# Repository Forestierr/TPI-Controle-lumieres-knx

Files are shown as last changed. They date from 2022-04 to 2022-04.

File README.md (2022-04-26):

# TPI_Forestier_Gestion_Lumiere_KNX #

Wiki: [Wiki](https://github.com/Forestierr/TPI-Controle-lumieres-knx/wiki)

Énoncé du travail d'examen: [Énoncé du travail](https://github.com/Forestierr/TPI-Controle-lumieres-knx/blob/main/1_Documentation/Enoncé%20du%20travail%20d'examen.pdf)

## Travail avant TPI ##

Wiki: [Wiki](https://github.com/Forestierr/Controle-lumieres-knx/wiki)

GitHub: [GitHub](https://github.com/Forestierr/Controle-lumieres-knx)

# Description du travail d'examen #

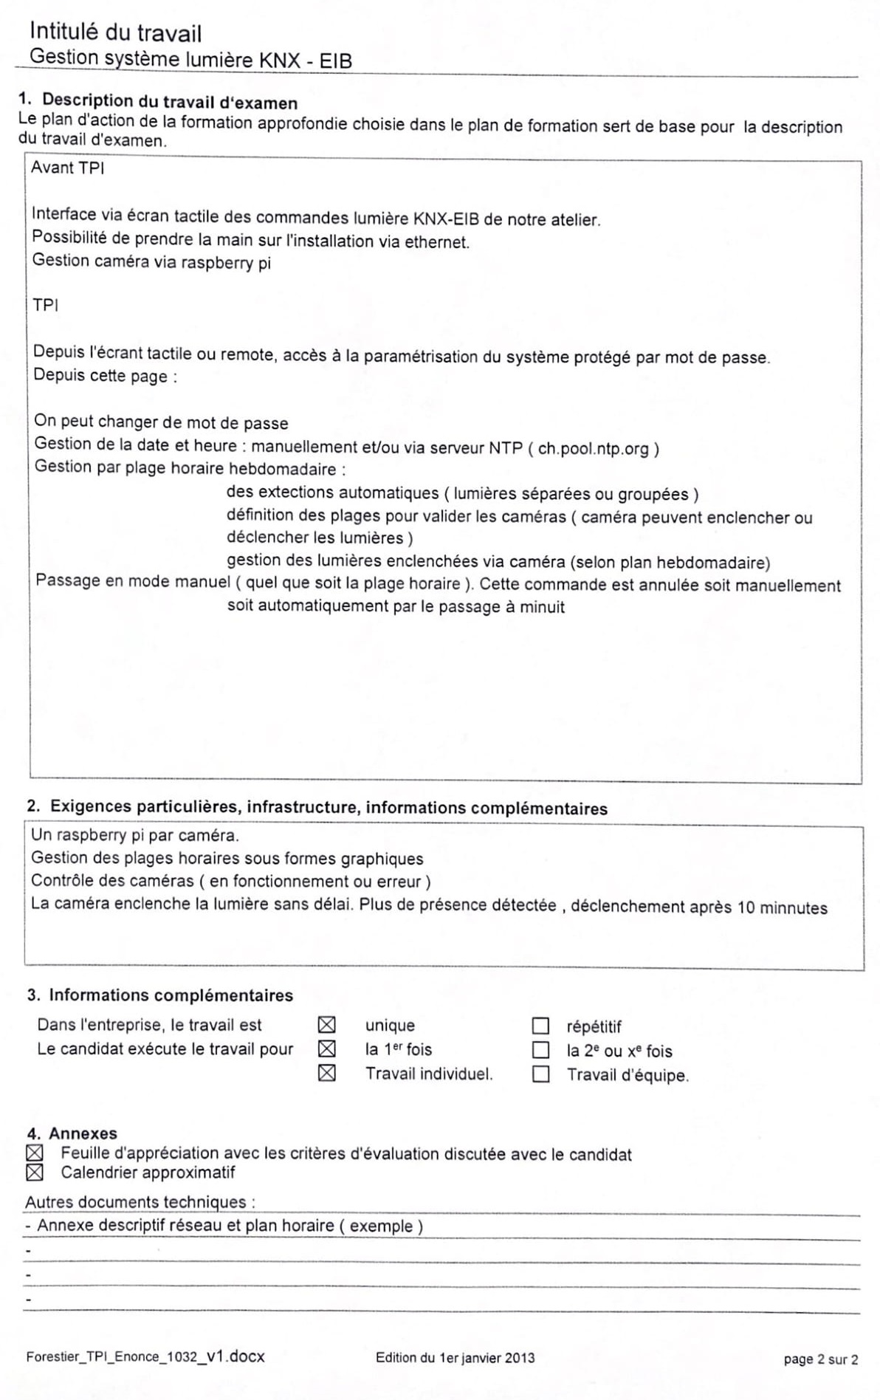
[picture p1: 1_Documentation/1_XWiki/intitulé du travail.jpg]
Cahier des charges


---

<div align="center">
    <i>Robin Forestier</i>
</div>

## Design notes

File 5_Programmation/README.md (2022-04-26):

# 5_Programmation #

Ce dossier contient l'entièreté de la programmation du projet.
Il y a deux sous dossier: camera et server. Le dosiier camera contient tous les codes et tous les testes pour le Rasperry Pi avec caméra.
Le dossier server contient les code pour le Raspberry Pi server (avec écran tactile).

---

Robin Forestier 2022

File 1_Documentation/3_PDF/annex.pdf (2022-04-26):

### Annex – Programmation – Caméra – Sélection Des Portes

5_Programmation/camera/Detetcion_Porte/door_setect.py

### Annex – Programmation – Caméra – Détection Des Portes

5_Programmation/camera/Detetcion_Porte/door_detect.py

### Annex – Programmation – Caméra – Détection Des Personnes

5_Programmation/camera/Detection_Personne/personne_detect.py

### Annex – Programmation – Caméra – Tracking Des Personnes

5_Programmation/camera/Detection_Personne/personne_tracking.py

### Annex – Programmation – Caméra – Détection Des Entrées

5_Programmation/camera/Detection_Entry/entry_detect.py

### Annex – Programmation – Caméra – Détection Des Personne 2

5_Programmation/camera/Detection_Personne_2/personne_detect.py

### Annex – Programmation – Caméra – Tracking Des Personne 2

5_Programmation/camera/Detection_Personne_2/personne_tracking.py

### Annex – Programmation – Caméra – Détection Des Entrées 2

5_Programmation/camera/Detection_Entry_2/entry_detect.py

### Annex – Programmation – Serveur – Main

5_Programmation/server/main.py

### Annex – Programmation – Serveur – WSGI

5_Programmation/server/wsgi.py

### Annex – Programmation – Serveur – Table

5_Programmation/server/table/table.py

### Annex – Programmation – Serveur – HTML – Login 2

5_Programmation/server/templates/login2.html

### Annex – Programmation – Serveur – HTML – Settings

5_Programmation/server/templates/settings.html

### Annex – Programmation – Serveur – CSS – Settings

5_Programmation/server/static/settings.css

### Annex – Programmation – Serveur – CSS – Login 2

5_Programmation/server/static/login2.css

### Annex – Programmation – Serveur – Test

5_Programmation/server/test/flask_test.py

### Annex – Programmation – Caméra – Test

5_Programmation/camera/test/main.py

### Annex – Programmation – Caméra – Test Communication

5_Programmation/camera/test/test_communication.py

### Annex – Planning

1_Documentation/Planning_TPI_FOR_v2.xls

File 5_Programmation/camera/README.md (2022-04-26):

# Caméra #

## Dossiers ##

### test ###

Dossier contenant un fichier de test d'OpenCV.
> cd test
> 
> python main.py

### Detection_Porte ###

**door_select.py** fichier utilisé pour sélectionner la position des portes.

**door_detect.py** fichier utilisé pour détecter les porte avec le template matching.

### Detection_Personne ##

**personne_detect.py** fichier utilisé pour détecter des personnes en mouvement (avec backgroundSubtractorKNN).

**personne_tracking.py** fichier utilisé pour calculer l'angle de déplacement d'une personne.

### Detection_Entry ###

**entry_detect.py** fichier utiliser pour détecter les entrées. Ce fichier utilise la detection des portes et des 
personnes.

### Detection_Personne_2 ###

Ce dossier contient le fichier de détection réaliser pour l'amélioration du système.
La détection se fait donc par le dessu de la porte ou par le côté.

**personne_detect.py** fichier utilisé pour détecter des personnes en mouvement (avec backgroundSubtractorMOG2).

### Detection_Entry_2 ###

Ce dossier contient le fichier de détection réaliser pour l'amélioration du système.
Il fonctionne avec **Detection_Personne_2**.

**entry_detect_2.py** fichier utiliser pour détecter les entrées. Ce fichier utilise la detection des portes et des
personnes.

---

Robin Forestier

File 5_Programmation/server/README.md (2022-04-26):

# Elo light control #

## But : ##

Le but de ce project est de controller les lumières de l'atelier avec un interface graphique sur l'écran tactile du Raspberry Pi 3B+.

## Test ##

./test/flask_test.py

Lancer ce fichier pour tester le serveur flask.

## launching the app ##

sudo python3 main.py

/!\ sudo est utilisé (sur linux) pour authoriser l'utilisaton du port 80.

Pour utiliser le server complétement référez vous aux XWiki.

## Liens ##

[Gitlab](http://172.16.32.230/Forestier/controle-des-lumieres-knx)

[XWiki](https://xwiki.serverelo.org/xwiki/bin/view/Centre%20de%20Formation%20ELO/Projets/Controle%20des%20lumières%20KNX/)

## ##

Robin Forestier 2021 / 2022

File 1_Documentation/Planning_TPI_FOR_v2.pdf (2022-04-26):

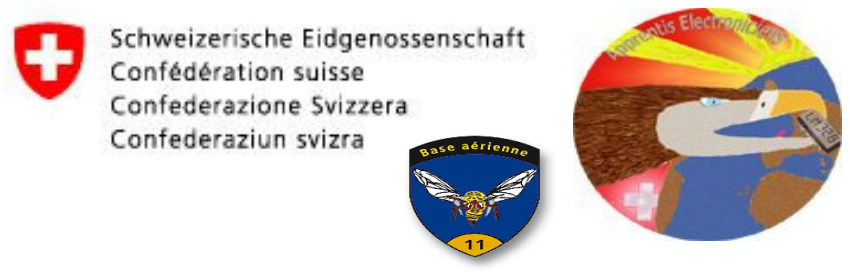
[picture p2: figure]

Tâches | Jours | Mon 07/Mar | Tue 08/Mar | Wed 09/Mar | Thu 10/Mar | Fri 11/Mar
Heures | Mat | Ap. Mi | Mat | Ap. Mi | Mat | Ap. Mi | Mat | Ap. Mi | Mat | Ap. Mi
Planification du projet

C

o

urs

E

P

SIC

### Robin Forestier

Correction et amélioration
Documentation | | | | | | Tot Sem | Total
Heures programmées | 08:00 | 08:00 | 08:00 | 00:00 | 00:00 | 24:00 | 24:00

Gestion des erreurs de communication

Communication via WIFI

Test de l'interface et optimisation

Mise en page CSS

Implémentation du mode manuelle

Création des tableaux de plage horaire

Création de la page HTML

Gestion de la date et de l'heure

Détection des portes
Détection des personnes
Détection des entrées et des sorties Ajustement pour la vision nocturne

Installation des Rasberry Pi

C

o

urs

E

P

SIC

Planning - Semaine 1 | Temps planifié Temps réel

Tâches | Jours | Mon 14/Mar | Tue 15/Mar | Wed 16/Mar | Thu 17/Mar | Fri 18/Mar
Heures | Mat | Ap. Mi | Mat | Ap. Mi | Mat | Ap. Mi | Mat | Ap. Mi | Mat | Ap. Mi
Planification du projet

### Robin Forestier

Test de l'interface et optimisation

Communication via WIFI

Gestion des erreurs de communication

Correction et amélioration

Documentation | | | | | | Tot Sem | Total
Heures programmées | 08:00 | 08:00 | 08:00 | 00:00 | 00:00 | 24:00 | 48:00

Mise en page CSS

Détection des portes

Détection des personnes

Détection des entrées et des sorties Ajustement pour la vision nocturne

Gestion de la date et de l'heure

Création de la page HTML

Création des tableaux de plage horaire

Implémentation du mode manuelle

Installation des Rasberry Pi

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
Planning – Semaine 2 | Temps planifié Temps réel

Tâches | Jours | Mon 21/Mar | Tue 22/Mar | Wed 23/Mar | Thu 24/Mar | Fri 25/Mar
Heures | Mat | Ap. Mi | Mat | Ap. Mi | Mat | Ap. Mi | Mat | Ap. Mi | Mat | Ap. Mi
Planification du projet

Installation des Rasberry Pi

### Robin Forestier

Communication via WIFI

Gestion des erreurs de communication

Correction et amélioration

Documentation | | | | | | Tot Sem | Total
Heures programmées | 08:00 | 08:00 | 08:00 | 00:00 | 00:00 | 24:00 | 72:00

Test de l'interface et optimisation

Création de la page HTML

Création des tableaux de plage horaire

Implémentation du mode manuelle

Mise en page CSS

Gestion de la date et de l'heure

Détection des entrées et des sorties Ajustement pour la vision nocturne

Détection des personnes

Détection des portes

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
Planning – Semaine 3 | Temps planifié Temps réel

Tâches | Jours | Mon 28/Mar | Tue 29/Mar | Wed 30/Mar | Thu 31/Mar | Fri 01/Apr
Heures | Mat | Ap. Mi | Mat | Ap. Mi | Mat | Ap. Mi | Mat | Ap. Mi | Mat | Ap. Mi
Planification du projet

Installation des Rasberry Pi

### Robin Forestier

Communication via WIFI

Gestion des erreurs de communication

Correction et amélioration

Documentation | | | | | | Tot Sem | Total
Heures programmées | 08:00 | 08:00 | 08:00 | 00:00 | 00:00 | 24:00 | 96:00

Test de l'interface et optimisation

Création de la page HTML

Création des tableaux de plage horaire

Implémentation du mode manuelle

Mise en page CSS

Gestion de la date et de l'heure

Détection des entrées et des sorties Ajustement pour la vision nocturne

Détection des personnes

Détection des portes

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
Planning – Semaine 4 | Temps planifié Temps réel

Tâches | Jours | Mon 04/Apr | Tue 05/Apr | Wed 06/Apr | Thu 07/Apr | Fri 08/Apr
Heures | Mat | Ap. Mi | Mat | Ap. Mi | Mat | Ap. Mi | Mat | Ap. Mi | Mat | Ap. Mi
Planification du projet

Installation des Rasberry Pi

Fin

d

u

T

PI

### Robin Forestier

C

o

urs

E

P

SIC

Communication via WIFI

Gestion des erreurs de communication

Correction et amélioration

Documentation | | | | | | Tot Sem | Total
Heures programmées | 08:00 | 08:00 | 00:00 | 00:00 | 00:00 | 16:00 | 112:00

Test de l'interface et optimisation

Création de la page HTML

Création des tableaux de plage horaire

Implémentation du mode manuelle

Mise en page CSS

Gestion de la date et de l'heure

Détection des entrées et des sorties Ajustement pour la vision nocturne

Détection des personnes

Détection des portes

C

o

urs

E

P

SIC

Planning – Semaine 5 | Temps planifié Temps réel

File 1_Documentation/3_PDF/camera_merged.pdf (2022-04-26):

1 """door_select.py | Robin Forestier | 07.03.2022
2
3 This file is used to select doors in images.
4 """
5
6 | import | | cv2
7 | import | | numpy | | as | | np
8 | import | | pickle
9
10
11 | class | | DoorSelect:
12 """The DoorSelect class is a class that contains a method that allows the user
| to select a door."""
13 | | def | | __init__(self, | | | | | img | | = | | None):
14 """ __init__ is the constructor of the class DoorSelect.
15 :param img: the image that will be used to select the doors. 16 :type img: numpy.ndarray
17 """
18
19 # the image
20 | | self.img | | | | = | | img
21
22
23 | | self.doors | | | | = | | []
24 """Doors
25 List containing the 4 corners coordinations of each door. 26 """
27
28 | | self.fleches | | | | = | | []
29 """Fleches
30 List containing the coordination of the arrowhead.
31 """
32
33 # number of point already placed (return to 0 after each door)
34 | | self.npoints | | | | = | | 0
35
36 | | if | | img | | is | | not | | None:
37 # a copy of the clean image (used when you delete a selection)
38 | | self.img_copy | | | | = | | img.copy()
39 cv2.namedWindow("door select")
40 | | cv2.setMouseCallback('door select', | | | | | | | self.mouse_event)
41 self.run()
42
43 | | def | | run(self):
44 """
45 [INFO] Doors selection phase.
46 [INFO] To select a door:
47 [INFO] 1. Left click the four corner of the door.
48 [INFO] 2. left click on the side where you enter the room through the door. 49 [INFO] Repeat these 2 steps as many times as you have doors.
50 [INFO] If you want to delete a selection, right click on it.
51 [INFO] Press < SPACE > when you are done.
52 """
53
54 print(self.run.__doc__)
55
56 # The loop is infinite until the user press the <SPACE> key.
57 | | while | | cv2.waitKey(1) | | | | | | | != | | 32:
58 | | cv2.imshow("door select", | | | | | | | self.img)
59
60 # check if doors are selected (with an arrow)
61 | | if | | len(self.doors) | | | | | | | % | | 4 | | == | 0 | and | len(self.fleches) | == | len(self.doors) | / | 4:
62 | | with | | open('doors.pickle', | | | | | 'wb') | | | as | | f:
63 # Save the list self.doors and self.fleches with pickle
64 | | save | | = | | (self.doors, | | | | | | self.fleches)
65 | | pickle.dump(save, | | | | | | | f)
66
67 print("[INFO] Selected doors successfully saved.\n")
68
69 | | i | | = | | 0
70 # This is a way to iterate over the list self.doors 4 by 4.
71 | | for | | door | | in | | zip(*[iter(self.doors)] | | | | | | | | * | 4):

72 | | arr | = | | np.array(door)
73 | | x, | | y, | | | w, | | | h | = | | cv2.boundingRect(arr)
74 #cv2.rectangle(self.img, (x, y), (x + w, y + h), (0, 255, 0), 2)
75 | | img_croped | = | | self.img_copy[y:y+h, | | | | | | | | | | x:x+w]
76 | | cv2.imwrite("door_{0}.png".format(i), | | | | | | | | | img_croped)
77 | | i | = | | i | | + | | 1
78
79 else:
80 print("[ERROR] No door select ! \n")
81
82 print("[INFO] Press < ENTER > to close the app.")
83 print("[INFO] Press < SPACE > to select a new door. \n") 84
85 # retry or close the app
86 | | while | True:
87 | | key | = | | cv2.waitKey(1)
88 | | if | key | | == | | 32: | | | # space
89 self.run()
90 | | elif | key | | == | | 13: | | | # enter
91 print("[INFO] Stop the app.") 92 cv2.destroyAllWindows()
93 break
94
95 | | def | sort_points(self, | | | | | door):
96 """sort_points is used for sorting the 4 corner of the door like that:
97 | 0 1
98 +----+
99 | | |
100 +----+
101 | 2 3
102
103 :param door: a list of four points that represent the four corners of the door 104 :type door: list
105 :return: a list of 4 points that represent the corners of the door.
106 :rtype: list
107 """
108
109 # It creates a numpy array of 4 rows and 2 columns.
110 | | rect | = | | np.zeros((4, | | | | | | 2), | | | dtype="float32")
111
112 # It's summing the y coordinates of the points.
113 | | s | = | | np.sum(door, | | | | | | axis=1)
114
115 # min -> corner 0
116 # max -> corner 2
117 | | rect[0] | | | | = | | door[np.argmin(s)]
118 | | rect[2] | | | | = | | door[np.argmax(s)]
119 # diff of the poits y
120
121 # It contains the difference between the y coordinates of the points.
122 | | diff | = | | np.diff(door, | | | | | | axis=1)
123 # min -> corner 1
124 # max -> corner 3
125 | | rect[1] | | | | = | | door[np.argmin(diff)]
126 | | rect[3] | | | | = | | door[np.argmax(diff)]
127
128 | | return | rect
129
130 | | def | draw_door(self):
131 """Draw the door outline and the arrow""" 132
133 | | n_door | = | | 0
134 # drawing of the 4 points arround the door
135 | | for | point | | in | | self.doors:
136 | | cv2.circle(self.img, | | | | | | | | point, | | 4, | | | (0, | | 0, | 255), | -1)
137 # drawing of the arrowhead
138 | | for | point | | in | | self.fleches:
139 | | cv2.circle(self.img, | | | | | | | | point, | | 4, | | | (0, | | 255, | 0), | -1)
140
141 # drawing of all the lines
142 | | for | door | | in | | zip(*[iter(self.doors)] | | | | | | | | * | 4):
143 # It's sorting the 4 points of the door in order to draw the door.

144 | | rect | = | self.sort_points(door)
145
146 # It's converting the points from float to integer.
147 | | rect | = | rect.astype(int)
148
149 # It's drawing the door.
150 | | cv2.line(self.img, | | | | | | tuple(rect[0]), | | | | | | | tuple(rect[1]), | | | | | (0, | | | | 0, | | | 255), | | 1)
151 | | cv2.line(self.img, | | | | | | tuple(rect[1]), | | | | | | | tuple(rect[2]), | | | | | (0, | | | | 0, | | | 255), | | 1)
152 | | cv2.line(self.img, | | | | | | tuple(rect[2]), | | | | | | | tuple(rect[3]), | | | | | (0, | | | | 0, | | | 255), | | 1)
153 | | cv2.line(self.img, | | | | | | tuple(rect[3]), | | | | | | | tuple(rect[0]), | | | | | (0, | | | | 0, | | | 255), | | 1)
154
155 # It's computing the center of the bottom of the door.
156 | | center | = | (int((rect[3][0] | | | | | | | | | + | | rect[2][0]) | | | | | / | | 2), | | | int((rect[3][1] | | | | | | +
| rect[2][1]) | | | | / | | 2))
157
158 | | cv2.circle(self.img, | | | | | | center, | | | 4, | | | (0, | | | 0, | | 255), | | | -1)
159
160 # This is a way to draw the arrowhead.
161 | | if | len(self.fleches) | | | | | >= | | n_door | | + | | 1:
162 | | cv2.line(self.img, | | | | | | center, | | | self.fleches[n_door], | | | | | | (255, | | | 0, | | | 0), | | | 2)
163
164 | | n_door | = | n_door | + | | 1
165
166 | | def | delete_door(self, | | | x, | | | y):
167 """Delete a door already selected by right click on it 168
169 :param x: The x-coordinate of the mouse-click
170 :type x: int
171 :param y: The y-coordinate of the point 172 :type y: int
173 """
174
175 | | n_door | = | 0
176 | | for | door | in | zip(*[iter(self.doors)] | | | | | | | | | * | | 4):
177 # sort the points
178 | | rect | = | self.sort_points(door)
179 | | rect | = | rect.astype(int)
180 # if you click between the point 0 and 3
181 | | if | rect[0][0] | | | | | < | | x | | < | | rect[2][0] | | | | | and | | rect[0][1] | | | | | | | < | y | < | rect[2][1]:
182 print("[INFO] Door deleted \n")
183
184 # delete the 4 points of the door
185 | | del(self.doors[n_door:n_door | | | | | | | + | | 4])
186
187 # if it's create delete the coresponding arrow
188 | | if | len(self.fleches) | | | | | >= | | (len(self.doors) | | | | | | | + | 4) | | | / | | 4:
189 | | del(self.fleches[int(n_door | | | | | | | / | | 4)])
190 else:
191 # if the arrow has not been created, the next point should not
| be the arrow.
192 | | self.npoints | | = | 0
193
194 | | self.img | | = | self.img_copy.copy()
195 self.draw_door()
196
197 | | n_door | = | n_door | + | | 4
198
199 | | def | mouse_event(self, | | | event, | | | x, | | | y, | | | flags, | | params):
200 """Execute when mouse is used on image.
201
202 :param event: The event that took place (left mouse button pressed, left
| mouse button released, mouse movement, etc)
203 :type event: int
204 :param x: The x-coordinate of the event
205 :type x: int
206 :param y: The y-coordinate of the click
207 :type y: int
208 :param flags: The flags are the optional parameters to the mouse callback
| function
209 :type flags: int
210 :param params: extra parameters passed to the callback function
211 :type params: int

212 """
213
214 # Checking if the left button of the mouse is pressed.
215 | | if | | event | | == | | cv2.EVENT_LBUTTONDOWN:
216 # outline selection
217 | | if | | self.npoints | | | | <= | | 3:
218 | | self.doors.append((x, | | | | | | | | | y))
219 | | self.npoints | | | | = | | self.npoints | | | | + | | 1
220 # fleche selection
221 | | elif | | self.npoints | | | | < | | 5:
222 | | self.fleches.append((x, | | | | | | | | | y))
223 | | self.npoints | | | | = | | self.npoints | | | | + | | 1
224
225 # new selection
226 | | if | | self.npoints | | | | >= | | 5:
227 | | self.npoints | | | | = | | 0
228
229 # This is a way to draw the door when the mouse is released.
230 | | elif | | event | | == | | cv2.EVENT_LBUTTONUP:
231 self.draw_door()
232
233 # Checking if the right button of the mouse is pressed.
234 | | if | | event | | == | | cv2.EVENT_RBUTTONDOWN:
235 | | self.delete_door(x, | | | | | | | y)
236
237
238 | if | | __name__ | | == | | '__main__':
239 # read the file video_d.avi
240 | | cap | | = | | cv2.VideoCapture(0)
241 # take the first img of the video
242 | | _, | | | img | | = | | cap.read()
243 | | img | | = | | cv2.resize(img, | | | | | | | (640, | | 480), | interpolation=cv2.INTER_AREA)
244 # create object DoorSelect
245 | | d | | = | | DoorSelect(img)
246

1 """door_detect.py | Robin forestier | 08.03.2022
2
3 This code is used for finding the door with the existing template create by < door_select.py >.
4 """
5
6 | import | | glob
7 | import | | cv2
8
9 # It's used to capture the video from the camera.
10 | cap | | = | | cv2.VideoCapture(0)
11
12
13 | def | | load_images_from_folder():
14 """Load all the template images from the current directory 15
16 :return: A list of images.
17 :rtype: list
18 """
19
20 # It's a function that return a list of all the files with the extension .png in
| the current directory.
21 | | filenames | | = | | glob.glob("*.png")
22 # Sort it by name
23 filenames.sort()
24 | | images | | = | | []
25
26 # It's a loop for loading all the images in the current directory.
27 | | for | | img | | in | | filenames:
28 | | n | | = | | cv2.imread(img)
29 | | if | | n | | is | | not | | None:
30 print("[INFO] Door template loaded.") 31 images.append(n)
32 else:
33 | | print("[Error] " | | | | + | | img | | + | " Not load.")
34
35 | | return | | images
36
37
38 | def | | detectDors(img, | | | | | template):
39 """We use template matching to detect the doors
40
41 :param img: The image we want to detect the template on 42 :type img: numpy.ndarray
43 :param template: the template image
44 :type template: numpy.ndarray
45 :return: the image with the rectangles around the detected doors, the max
| location of the template and the width and
46 height of the template.
47 :rtype: numpy.ndarray, tuple, tuple
48 """
49
50 # It's converting the image from BGR to gray.
51 | | gray_img | | = | | cv2.cvtColor(img, | | | | | | cv2.COLOR_BGRA2GRAY)
52 # It's making a copy of the image to draw the rectangles on it.
53 | | copy | | = | | img.copy()
54
55 # for each template
56 | | for | | tmp | | in | | template:
57 # It's converting the template from BGR to gray.
58 | | tmp | | = | | cv2.cvtColor(tmp, | | | | | | cv2.COLOR_BGRA2GRAY)
59 # It's getting the width and the height of the template.
60 | | w, | | | h | | = | | tmp.shape[::-1]
61 # It's matching the template to the image.
62 | | res | | = | | cv2.matchTemplate(gray_img, | | | | | | tmp, | | cv2.TM_CCOEFF_NORMED)
63 # Normalize result
64 | | cv2.normalize(res, | | | | | | | res, | | 0, | | 1, | | | cv2.NORM_MINMAX, | | -1)
65 # Detect the max location.
66 | | (_, | | | | max_val, | | | _, | | max_loc) | | = | | cv2.minMaxLoc(res)
67
68 # Draw the rect around the detected template
69 | | cv2.rectangle(copy, | | | | | | | max_loc, | | (max_loc[0] | | | | | + | w, | max_loc[1] | + | h), | (255, | 0, | 0), | 2)

70 | | cv2.rectangle(copy, | | | | | | | (max_loc[0] | | | | | | + | 1, | | max_loc[1] | | + | | 1), | | (max_loc[0] | | | | + | w,
| max_loc[1] | | | | | + | | int(h | | | | / | | 2)), | | (255,255,0), | | | | -1)
71 | | cv2.rectangle(copy, | | | | | | | (max_loc[0] | | | | | | + | 1, | | max_loc[1] | | + | | h | - | | 1), | | (max_loc[0] | | | + | w,
| max_loc[1] | | | | | + | | int(h | | | | / | | 2) | | + | 1), | | (0, | | 255, | | 255), | | | -1)
72
73 | | return | | copy, | | | max_loc, | | | w, | | | h
74
75
76 | if | | __name__ | | == | | '__main__':
77 # It's loading all the template images from the current directory.
78 | | template | | = | | load_images_from_folder()
79
80 | | while | | True:
81 # It's getting the image from the camera and storing it in the variable `img`.
82 | | _, | | | img | | = | | cap.read()
83
84 # resize image form (2592, 1944) -> (640, 480)
85 | | img | | = | | cv2.resize(img, | | | | | | | (640, | | | 480), | | interpolation=cv2.INTER_AREA)
86 | | result | | = | | detectDors(img, | | | | | template)
87 # It's showing the image with the rectangles around the detected template.
88 | | cv2.imshow("Result", | | | | | | | result)
89
90 # It's waiting for the user to press the key `q` to quit the program.
91 | | if | | cv2.waitKey(1) | | | | | | | == | | ord("q"):
92 break
93
94 # It's closing the camera and the windows. 95 cv2.destroyAllWindows()
96 cap.release()
97

1 """personne_detect.py | Robin Forestier | 8.03.2022
2
3 Detecting moving personne on video.
4 """
5
6 # import OpenCV
7 | import | | cv2
8
9
10 | class | | PersonneDetect:
11 """This class is used to detect people in a video stream."""
12 | | def | | __init__(self):
13 | | self.img | | | | = | | []
14 | | self.copy | | | | = | | []
15 | | self.detected | | | | = | | []
16 | | self.backSub | | | | = | | cv2.createBackgroundSubtractorKNN(history=100,
| dist2Threshold=500.0, | | | | | detectShadows=True)
17
18 | | def | | img_to_gray(self):
19 """If the image is in color, convert it to grayscale """ 20
21 | | if | | len(self.img.shape) | | | | | | | == | | 3:
22 | | self.img | | | | = | | cv2.cvtColor(self.img, | | | | | | | cv2.COLOR_BGR2GRAY)
23 else:
24 pass
25
26 | | def | | contour_detect(self, | | | | | threshold):
27 """Detect the biggest contours in the image and store them in a list 28
29 :param threshold: The threshold image that was used
30 :type threshold: numpy.ndarray
31 """
32
33 | | self.detected | | | | = | | []
34
35 # Finding contours in the image.
36 | | cnts, | | | hierarchy | | = | | cv2.findContours(threshold, | | | | | cv2.RETR_EXTERNAL,
| cv2.CHAIN_APPROX_SIMPLE)
37
38 # for eache contour
39 | | for | | cnt | | in | | cnts:
40 # if the perimeter is bigger than 100
41 | | if | | 100 | | < | | cv2.arcLength(cnt, | | | | | True) | | | < | | 2000:
42 # creting a bounding rect around it.
43 # Creating a bounding rectangle around the contour.
44 | | x, | | | y, | | | w, | | h | = | | cv2.boundingRect(cnt)
45 # store it
46 | | self.detected.append([x, | | | | | | | | y, | | w, | | | h])
47 # draw a green rectangle.
48 | | cv2.rectangle(self.copy, | | | | | | | | (x, | | | y), | | | (x | | | + | | w, | y | + | h), | (0, | 255, | 0), | 3)
49
50 | | def | | personne_detect(self, | | | | | img):
51 """Detecting personne on image with background subtraction (KNN)
52
53 :param img: The input image
54 :type img: numpy.ndarray
55 :return: the copy of the image with the green rectangle around the detected
| personne.
56 :rtype: numpy.ndarray
57 """
58
59 | | self.img | | | | = | | img
60 | | self.copy | | | | = | | img.copy()
61
62 # Converting the image to grayscale if it is in color. 63 self.img_to_gray()
64 # Applying the background substractor to the image.
65 | | fgmask | | = | | self.backSub.apply(self.img)
66 # Blurring the image to remove the noise.
67 | | blurImage | | = | | cv2.GaussianBlur(fgmask, | | | | | (5, | | | | 5), | | | 0)
68 # Thresholding the image to make it binary.
69 | | _, | | | th | | = | | cv2.threshold(blurImage, | | | | | 1, | | | 255, | | | cv2.THRESH_BINARY)

70
71 # Realising 3 morphology transformation to clear the image of impure pixel. 72 # To dilate the shape and close it.
73 # kernel = np.ones((5, 5), np.uint8)
74 | | kernel | | = | | cv2.getStructuringElement(cv2.MORPH_ELLIPSE, | | | | | (7, | | | | 7))
75 | | th | | = | | cv2.morphologyEx(th, | | | | cv2.MORPH_OPEN, | | | | kernel)
76 | | th | | = | | cv2.morphologyEx(th, | | | | cv2.MORPH_CLOSE, | | | | kernel)
77 | | th | | = | | cv2.dilate(th, | | | | kernel, | | iterations=1)
78
79 # call contour_detect for detect them.
80 self.contour_detect(th)
81
82 # return th copy of the img (with the green rectangle)
83 | | return | | self.copy
84
85
86 | if | | __name__ | | == | | '__main__':
87 # Opening the video file.
88 | | cap | | = | | cv2.VideoCapture("video_d.avi")
89 # Creating an object of the class PersonneDetect.
90 | | p | | = | | PersonneDetect()
91
92 | | while | | True:
93 # Reading the next frame from the video file.
94 | | _, | | | img | | = | cap.read()
95 # Resizing the image to a smaller size to make the algorithm faster.
96 | | img | | = | | cv2.resize(img, | | | | (640, | | | 480), | | | interpolation=cv2.INTER_AREA)
97
98 # Calling the function `personne_detect` of the class `PersonneDetect` and
| passing the image `img` as argument.
99 | | img | | = | | p.personne_detect(img)
100
101 # Showing the image in a window named "img".
102 | | cv2.imshow("img", | | | | | | img)
103
104 # Stop the program when the user press the key `q`.
105 | | if | | cv2.waitKey(50) | | | | | == | ord("q"):
106 break
107
108 # Closing the video file and destroying all the windows. 109 cv2.destroyAllWindows()
110 cap.release()
111

1 """ personne_tracking.py | Robin Forestier | 09.03.2022
2
3 After Personne detection we want to track it.
4 For tracking the displacement of a mooving object, I start by calculate his centroide. 5 After I save his last centroide to ave 2 points by mooving object.
6 With this points a calculate the euclidean distance to find the nearest.
7 And I finishe by calculate the angle of displacement.
8 """
9
10 | import | | cv2
11 | import | | math
12 | import | | numpy | | as | | np
13
14 # It's importing the PersonneDetect class from the personne_detect.py file.
15 | from | | personne_detect | | import | | PersonneDetect
16
17 | class | | PersonneTracking:
18 """Is used for track the trajectory of any people detected by PersonneDetect."""
19 | | def | | __init__(self):
20 """The function initializes the class"""
21 | | self.img | | | | = | | []
22 | | self.prev_img | | | | = | | []
23 | | self.centroide | | | | = | | []
24 | | self.centroide_lp | | | | = | | []
25
26 | | self.angle | | | | = | | []
27
28 | | def | | calc_centroide(self, | | | | | img, | | | rects):
29 """Calculate the centroid of the bounding rect
30
31 :param img: The image on which the contour was found
32 :type img: numpy.ndarray
33 :param rects: a list of tuples, where each tuple is (x, y, w, h) 34 :type rects: list
35 """
36
37 | | self.img | | | | = | | img
38 # save the last centroid
39 | | self.centroide_lp | | | | = | | self.centroide
40 | | self.centroide | | | | = | | []
41
42 | | for | | rect | | in | | rects:
43 # It's the coordinates of the point where the line is drawn.
44 | | x | | = | | int(rect[0] | | | | | | | + | | (rect[2] | | | | / | 2))
45 | | y | | = | | int(rect[1] | | | | | | | + | | (rect[3] | | | | / | 2))
46 self.centroide.append((x,y))
47 # It's drawing a circle on the image.
48 | | cv2.circle(self.img, | | | | | | | | | (x, | | | | y), | | 2, | | (0,0, | | | | 255), | | -1)
49
50 # It's calculating the euclidean distance of each centroid and last centroid
| for predict the move of a person.
51 self.centroide_last_pose()
52
53 | | def | | centroide_last_pose(self):
54 """Calculate the angle of displacement of each centroid and last centroid""" 55
56 | | self.angle | | | | = | | []
57
58 | | centroide_np | | = | | np.array(self.centroide_lp)
59
60 | | if | | self.centroide_lp | | | | and | | self.centroide:
61 | | for | | last_point | | in | | self.centroide:
62 # This is the code that is used to find the index of the minimum
| value in the array.
63 | | idx | | = | | np.array([np.linalg.norm(x | | | | | | | | | | | + | y) | | for | | (x, | | y) | | in | centroide_np | -
| last_point]).argmin()
64
65 | | cv2.circle(self.img, | | | | | | | | | last_point, | | | 2, | | (255, | | | 0, | | 0), | | -1)
66 | | cv2.line(self.img, | | | | | | | | | last_point, | | | self.centroide_lp[idx], | | | | | (255, | | | 255,
| 0), | | | 5, | | | cv2.LINE_AA)
67
68 # It's calculating the angle of the line between the two points.

69 | | y | | = | | last_point[1] | | | | | - | self.centroide_lp[idx][1]
70 | | x | | = | | last_point[0] | | | | | - | self.centroide_lp[idx][0]
71 | | angle | | = | | math.atan2(y, | | | | | | x) | | * | 180 | / | math.pi
72
73 # It's making sure that the angle is between 0 and 360 degrees.
74 | | if | | angle | | < | | 0:
75 | | angle | | = | | 360 | | + | | angle
76
77 # add it to the list angle 78 self.angle.append(angle)
79
80 | if | | __name__ | | == | | '__main__':
81 # It's using the video file to capture the frames.
82 | | cap | | = | | cv2.VideoCapture('video_d.mp4')
83
84 # It's creating an object of the class PersonneDetect.
85 | | p | | = | | PersonneDetect()
86 # It's creating an instance of the class PersonneTracking.
87 | | pt | | = | | PersonneTracking()
88
89 | | while | | True:
90 # This is a way to reset the video to the first frame if the video is
| finished.
91 | | if | | cap.get(cv2.CAP_PROP_POS_FRAMES) | | | | | | | | == | cap.get(cv2.CAP_PROP_FRAME_COUNT):
92 | | cap.set(cv2.CAP_PROP_POS_FRAMES, | | | | | | | | | 0)
93
94 # It's getting the image from the video.
95 | | _, | | | img | | = | | cap.read()
96
97 # It's using the PersonneDetect class to detect people in the image.
98 | | result | | = | | p.personne_detect(img)
99 # It's calculating the centroid of the bounding rect of the detected people.
100 | | pt.calc_centroide(result, | | | | | | | p.detected)
101
102 # It's showing the image on the screen.
103 | | cv2.imshow("result detect", | | | | | | | result)
104
105 | | prev | | = | | img
106
107 # It's breaking the loop when the user press the `q` key.
108 | | if | | cv2.waitKey(700) | | | | | | | == | ord('q'):
109 break
110
111 # It's closing the window and release the capture. 112 cv2.destroyAllWindows()
113 cap.release()

1 | """entry_detect.py | Robin Forestier | 09.03.2022
2
3 | This file is used to detect entry and exit. It uses DoorSelect & PersonneDetect &
PersonneTracking.
4 | """
5
6 | import | | math
7 | import | | pickle
8 | import | | time
9 | from | | datetime | | import | | datetime
10 | from | | os | | import | | path
11
12 | import | | cv2
13 | import | | numpy | | as | | np
14 | import | | requests
15
16 | # import personally module
17 | from | | sample.door_select | | | | import | | DoorSelect
18 | from | | sample.personne_detect | | | | import | | PersonneDetect
19 | from | | sample.personne_tracking | | | | import | | PersonneTracking
20
21
22 | class | | DetectEntry:
23 | | """DetectEntry class is used to detect entry and exit."""
24 | | def | | __init__(self, | | | | | frame, | doors, | | fleches):
25 | | """The function takes in the frame, the doors and the arrows to calcul of a
| personne is going in or out.
26
27 | :param frame: The image frame that the camera captured
28 | :type frame: numpy.ndarray
29 | :param doors: a list of tuples, each tuple is a door, with the first element
| being the x-coordinate of the
30 | center of the door, and the second element being the y-coordinate of the
| center of the door
31 | :type doors: list
32 | :param fleches: a list of tuples, each tuple is a pair of points, the first
| point is the center of the arrow,
33 | the second is the tip of the arrow
34 | :type fleches: list
35 | """
36
37 | | self.img | | | | = | | frame
38 | | self.doors | | | | = | | doors
39 | | self.fleches | | | | = | | fleches
40
41 | | self.angle | | | | = | | []
42 | | self.angle2 | | | | = | | []
43
44 | | def | | verify_door_pos(self):
45 | | | | # TODO add door_detect
46 | | pass
47
48 | | def | | calculate(self, | | | | | d_select):
49 | | """Calculate the angle between the center of the door and the arrow
50
51 | :param d_select: the door_select object
52 | :type d_select: DoorSelect
53 | """
54
55 | | n_door | | = | | 0
56
57 | | # Used to set the image and the doors and arrows position to the DoorSelect
| object.
58 | | d_select.img | | | | = | | frame
59 | | d_select.doors | | | | = | | pos
60 | | d_select.fleches | | | | = | | f_pos
61
62 | | for | | door | | in | | zip(*[iter(self.doors)] | | | | | | * | 4):
63 | | rect | | = | | np.zeros((4, | | | | | 2), | | dtype="float32")
64
65 | | # Summing the door points.
66 | | s | | = | | np.sum(door, | | | | | axis=1)

67 | | # It's calculating the minimum and maximum value of the door.
68 | | rect[0] | | | | = | | door[np.argmin(s)]
69 | | rect[2] | | | | = | | door[np.argmax(s)]
70
71 | | # It's calculating the difference between the door points.
72 | | diff | = | | np.diff(door, | | | | | | | axis=1)
73 | | # It's calculating the minimum and maximum value of the door.
74 | | rect[1] | | | | = | | door[np.argmin(diff)]
75 | | rect[3] | | | | = | | door[np.argmax(diff)]
76
77 | | # It's converting the rect from float to int.
78 | | rect | = | | rect.astype(int)
79
80 | | # It's calculating the center of th bottom of the door.
81 | | center | = | | (int((rect[3][0] | | | | | | | | | + | | rect[2][0]) | | | | | | / | 2), | | int((rect[3][1] | +
| rect[2][1]) | | | | | | / | | 2))
82
83 | | # It's calculating the angle between the center of the door and the
| bottom of the door.
84 | | y | = | | center[1] | | | | | - | | rect[2][1]
85 | | x | = | | center[0] | | | | | - | | rect[2][0]
86 | | angle | = | | math.atan2(y, | | | | | | | x) | | * | | 180 | | / | | math.pi
87
88 | | # It's making sure that the angle is between 0 and 360.
89 | | if | angle | | < | | 0:
90 | | angle | = | | 360 | | + | | angle
91
92 | | self.angle.append(angle)
93
94 | | # It's calculating the angle between the center of the door and the tip
| of the arrow.
95 | | y | = | | center[1] | | | | | - | | self.fleches[n_door][1]
96 | | x | = | | center[0] | | | | | - | | self.fleches[n_door][0]
97 | | angle2 | = | | math.atan2(y, | | | | | | | x) | | * | | 180 | | / | | math.pi
98
99 | | # It's making sure that the angle is between 0 and 360.
100 | | if | angle2 | | < | | 0:
101 | | angle2 | = | | 360 | | + | | angle2
102
103 | | self.angle2.append(angle2)
104
105 | | n_door | = | | n_door | | + | | 1
106
107 | | def | calc_in_out(self, | | | | | frame, | | | d_select, | | tracking, | | | info):
108 | | """Calculate if the person is going inside or outside
109
110 | :param frame: the frame from your video file or directly from your webcam
111 | :type frame: numpy.ndarray
112 | :param d_select: the door selection object
113 | :type d_select: DoorSelect
114 | :param tracking: the PersonneTracking object
115 | :type tracking: PersonneTracking
116 | :param info: an object of the Info class, which is used to store information
| about the people detected in the frame
117 | :type info: Info
118 | """
119
120 | | # It's drawing the doors on the frame.
121 | | d_select.img | | | = | | frame
122 | | d_select.draw_door()
123
124 | | n_door | = | | 0
125
126 | | for | door | | in | | zip(*[iter(d_select.doors)] | | | | | | | | * | | 4):
127 | | door | = | | np.array(door)
128 | | x, | | y, | | | w, | | | h | | = | cv2.boundingRect(door)
129
130 | | n | = | | 0
131
132 | | for | a | | in | | tracking.angle:
133 | | # It's checking if the person is in the door.
134 | | if | x | | < | | tracking.centroide[n][0] | | | | | | | | < | | x | | + | | w | and | y | <

| tracking.centroide[n][1] | | | | | | < | | y | | + | | h:
135 | | if | | self.angle[n_door] | | | | - | | 180 | | < | | 0:
136 | | angle2 | | = | 360 | - | (self.angle[n_door] | | | | | | | | + | | 180)
137 | | else:
138 | | angle2 | | = | self.angle[n_door] | | | | | - | | 180
139
140 | | if | | 10 | < | a | - | | angle2 | | < | | 170:
141 | | if | | self.angle2[n_door] | | | | - | | angle2 | | < | | 170:
142 | | info.queue.append([time.time(), | | | | | | | | 0, | | | n_door, | | | n])
143 | | else:
144 | | info.queue.append([time.time(), | | | | | | | | 1, | | | n_door, | | | n])
145 | | elif | | 190 | < | a | - | | angle2 | | < | | 350:
146 | | if | | self.angle2[n_door] | | | | - | | angle2 | | < | | 170:
147 | | info.queue.append([time.time(), | | | | | | | | 1, | | | n_door, | | | n])
148 | | else:
149 | | info.queue.append([time.time(), | | | | | | | | 0, | | | n_door, | | | n])
150 | | else:
151 | | pass
152
153 | | n | | = | n | + | 1
154 | | n_door | | = | n_door | + | 1
155
156
157 | class | | info:
158 | | """class info is used for sorting the value from calc_in_out (class
| DetectEntry)"""
159 | | def | | __init__(self):
160 | | """is a list of the last in/out value.
161 | [time, in (1) / out (0), door_num, personne_num]
162 | """
163 | | self.queue | | | = | []
164
165 | | def | | verify(self):
166 | | """Verify check all value in queue list.
167 | First I delete all value is too old (more than 5sec).
168 | After if we have 3 or more same detection, a validation is sent (return 0 or
| 1)
169
170 | :return: 0 or 1
171 | :rtype: int
172 | """
173
174 | | # It's checking if there is more than 3 detection.
175 | # | If there is, it's checking which door has the most detection.
176 | # | If there is more than one door with the same number of detection, it's
| checking which person is the
177 | | # closest to the center of the door.
178 | # | If there is only one door with the most detection, it's checking if the
person is going inside or outside.
179 | # | If the person is going inside, it's sending 1 to the server.
180 | # | If the person is going outside, it's sending 0 to the server.
181 | if | len(self.queue) | | | >= | 3:
182 | # It's converting the queue list to a numpy array.
183 | out | = | np.array(self.queue).T
184 | temp_ex | = | []
185
186 | # It's converting the array to int.
187 | out | = | out.astype(int)
188
189 | for | t | in | out[0]:
190 | if | t | < | out[0][len(self.queue) | | | | | | - | 1] | - | 5:
191 | temp_ex.append(np.where(out[0] | | | | | | == | | t))
192
193 | # It's deleting the value in the array that are in temp_ex.
194 | out | = | np.delete(out, | | | temp_ex, | | axis=1)
195
196 | inout | = | np.bincount(out[1]).argmax()
197
198 | if | max(np.bincount(out[1])) | | | | | <= | | max(np.bincount(out[2])) | | | | | and | \
199 | max(np.bincount(out[1])) | | | | | <= | max(np.bincount(out[3])):
200 | self.queue | | = | []
201

202 | | # It's returning the value of the verification of the queue list.
203 | | return | | inout
204
205
206 | def | | send(info):
207 | | """Send the data to the server
208
209 | :param info: the information to send
210 | :type info: int
211 | """
212
213 | | # It's getting the current time.
214 | | t | | = | | datetime.now()
215 | | current_time | | = | | t.strftime("%H:%M")
216
217 | | # It's opening the file /sys/class/thermal/thermal_zone0/temp and reading the
| temperature.
218 | | try:
219 | | with | | open('/sys/class/thermal/thermal_zone0/temp', | | | | | 'r') | | | as | | ftemp:
220 | | temp | | = | | int(int(ftemp.read()) | | | | | | | | | / | | 1000)
221 | | except | | OSError:
222 | | temp | | = | | 0
223
224 | | # It's creating a string that will be sent to the server.
225 | | data | | = | | "{}{:03d}{}".format(current_time, | | | | | | | temp, | | | info)
226 | | data | | = | | {'data': | | | | '$,RPWCSD,{:03d},{},0*'.format(len(data), | | | | | | | | | data)}
227
228 | | try:
229 | | # It's sending the data to the server.
230 | | r | | = | | requests.post("http://172.16.32.133/camera", | | | | | | | data=data, | | | | | timeout=0.5)
231
232 | | # This is checking if the status code is bigger than 299. If it is, it's
| printing an error message.
233 | | if | | r.status_code | | | | > | | 299:
234 | | print("[Error] Communication error")
235 | | else:
236 | | # It's getting the data from the server.
237 | | data | | = | | r.text
238 | | # if the data is a correct trame ($,...,*)
239 | | if | | data[0] | | | | | == | | "$" | | and | | data[::-1][0] | | | | | | == | "*":
240 | | data | | = | | data.split(',')
241
242 | | # Communication OK
243 | | if | | data[1] | | | | | == | | "RPWCOK":
244 | | print("ok")
245 | | # Communication Error
246 | | if | | data[1] | | | | | == | | "RPWCER":
247 | | print("[ERROR] The cam had send a bad trame.")
248
249 | | # It's catching the error if the server is not available.
250 | | except | | requests.exceptions.RequestException | | | | | | as | | e:
251 | | print(e)
252
253
254 | if | | __name__ | | == | | '__main__':
255 | | # It's opening the webcam.
256 | | cap | | = | | cv2.VideoCapture(0)
257
258 | | # It's getting the frame from the webcam.
259 | | _, | | | frame | | = | | cap.read()
260
261 | | # It's resizing the frame to 640x480.
262 | | frame | | = | | cv2.resize(frame, | | | | | | | (640, | | | | 480), | | | interpolation=cv2.INTER_AREA)
263
264 | | # This is checking if the file "doors.pickle" exists. If it doesn't, it's
| creating a new DoorSelect object and
265 | # | saving the doors and the arrows position in the file "doors.pickle".
266 | # | If the file "doors.pickle" exists, it's loading the data from the file.
267 | if | not | path.exists("doors.pickle"):
268 | d_select | = | DoorSelect(frame)
269 | pos | = | d_select.doors
270 | f_pos | = | d_select.fleches

271 | | else:
272 | | d_select | = | | DoorSelect()
273 | | with | open('doors.pickle', | | | | | 'rb') | | as | | f:
274 | | pos, | | f_pos | | = | | pickle.load(f)
275
276 | | # It's creating a PersonneDetect object and storing it in the variable `detect`.
277 | | detect | = | | PersonneDetect()
278 | | # It's creating a PersonneTracking object and storing it in the variable
| `tracking`.
279 | | tracking | = | | PersonneTracking()
280 | | # It's creating an object of the class DetectEntry and storing it in the
| variable `entry`.
281 | | entry | = | | DetectEntry(frame, | | | | pos, | | | f_pos)
282 | | # It's calculating the angle between the center of the door and the arrow.
283 | | entry.calculate(d_select)
284 | | # It's creating an object of the class `info` and storing it in the variable
| `inf`.
285 | | inf | = | | info()
286
287 | | while | True:
288 | | # This is checking if the video is over. If it is, it's reseting the frame
| to the first frame.
289 | | if | cap.get(cv2.CAP_PROP_POS_FRAMES) | | | | | | | | == | | cap.get(cv2.CAP_PROP_FRAME_COUNT):
290 | | cap.set(cv2.CAP_PROP_POS_FRAMES, | | | | | | | 0)
291
292 | | # It's getting the frame from the webcam.
293 | | _, | | frame | | = | | cap.read()
294
295 | | # It's resizing the frame to 640x480.
296 | | frame | = | | cv2.resize(frame, | | | | | | (640, | | | 480), | interpolation=cv2.INTER_AREA)
297
298 | | # It's detecting people in the frame.
299 | | frame | = | | detect.personne_detect(frame)
300 | | # It's calculating the centroid of the detected people.
301 | | tracking.calc_centroide(frame, | | | | | | detect.detected)
302 | | # It's calculating if the person is going inside or outside.
303 | | entry.calc_in_out(frame, | | | | | | d_select, | | tracking, | | | inf)
304
305 | | # It's checking if the person is going inside or outside.
306 | | # If the person is going inside, it's sending 1 to the server.
307 | | # If the person is going outside, it's sending 0 to the server.
308 | | inout | = | | inf.verify()
309
310 | | if | inout | | == | | 1:
311 | | print("[INFO] Entrée")
312 | | send(inout)
313 | | elif | inout | | == | | 0:
314 | | print("[INFO] Sortie")
315 | | send(inout)
316
317 | | # It's showing the image in a window.
318 | | cv2.imshow("image", | | | | | | frame)
319
320 | | # It's checking if the user press the key "q". If it is, it's breaking the
| loop.
321 | | if | cv2.waitKey(100) | | | | | | == | | ord("q"):
322 | | break
323
324 | | # It's closing the webcam and the window.
325 | | cv2.destroyAllWindows()
326 | | cap.release()
327

1 """personne_detect.py | Robin Forestier | 28.03.2022
2
3 [WARN] The camera is placed on top of the door.
4
5 Detecting moving personne on video.
6 """
7
8 # import OpenCV
9 | import | | cv2
10 | import | | numpy | | as | | np
11
12 | class | | PersonneDetect:
13 """This class is used to detect people in a video stream."""
14 | | def | | __init__(self):
15 | | self.img | | | | = | | []
16 | | self.copy | | | | = | | []
17 | | self.detected | | | | = | | []
18 | | self.backSub | | | | = | | cv2.createBackgroundSubtractorKNN(history=100,
| dist2Threshold=500.0, | | | | | detectShadows=False)
19
20 | | def | | img_to_gray(self):
21 """If the image is in color, convert it to grayscale """ 22
23 | | if | | len(self.img.shape) | | | | | | | == | | 3:
24 | | self.img | | | | = | | cv2.cvtColor(self.img, | | | | | | | cv2.COLOR_BGR2GRAY)
25 else:
26 pass
27
28 | | def | | contour_detect(self, | | | | | threshold):
29 """Detect the biggest contours in the image and store them in a list 30
31 :param threshold: The threshold image that was used
32 :type threshold: numpy.ndarray
33 """
34
35 | | self.detected | | | | = | | []
36
37 # Finding contours in the image.
38 | | cnts, | | | hierarchy | | = | | cv2.findContours(threshold, | | | | | cv2.RETR_EXTERNAL,
| cv2.CHAIN_APPROX_SIMPLE)
39
40 # for eache contour
41 | | for | | cnt | | in | | cnts:
42 # if the perimeter is bigger than 100
43 | | if | | 200 | | < | | cv2.arcLength(cnt, | | | | | True) | | | < | 2000:
44 # creting a bounding rect around it.
45 # Creating a bounding rectangle around the contour.
46 | | x, | | | y, | | | w, | | h | = | | cv2.boundingRect(cnt)
47 # store it
48 | | self.detected.append([x, | | | | | | | | y, | | w, | | | h])
49 # draw a green rectangle.
50 | | cv2.rectangle(self.copy, | | | | | | | | (x, | | | y), | | | (x | | + | w, | y | + | h), | (0, | 255, | 0), | 3)
51
52 | | def | | personne_detect(self, | | | | | img):
53 """Detecting personne on image with background subtraction (KNN)
54
55 :param img: The input image
56 :type img: numpy.ndarray
57 :return: the copy of the image with the green rectangle around the detected
| personne.
58 :rtype: numpy.ndarray
59 """
60
61 | | self.img | | | | = | | img
62 | | self.copy | | | | = | | img.copy()
63
64 # Converting the image to grayscale if it is in color. 65 self.img_to_gray()
66 # Applying the background substractor to the image.
67 | | fgmask | | = | | self.backSub.apply(self.img)
68 # Blurring the image to remove the noise.
69 | | blurImage | | = | | cv2.GaussianBlur(fgmask, | | | | | (5, | | | | 5), | | 0)

70 # Thresholding the image to make it binary.
71 | | _, | | | th | | = | cv2.threshold(blurImage, | | | 1, | | 255, | cv2.THRESH_BINARY)
72
73 # Realising 4 morphology transformation to clear the image of impure pixel. 74 # To dilate the shape and close it.
75 | | kernel | | = | | np.ones((9, | | | | 9), | np.uint8)
76 #kernel = cv2.getStructuringElement(cv2.MORPH_ELLIPSE, (9, 9))
77 | | cv2.imshow("th", | | | | | | th)
78 # th = cv2.erode(th, kernel, iterations=1)
79 # th = cv2.morphologyEx(th, cv2.MORPH_OPEN, kernel)
80 | | th | | = | | cv2.morphologyEx(th, | | | | cv2.MORPH_CLOSE, | | kernel)
81 | | th | | = | | cv2.dilate(th, | | | | kernel, | iterations=2)
82 | | th | | = | | cv2.morphologyEx(th, | | | | cv2.MORPH_CLOSE, | | kernel)
83 | | cv2.imshow("t", | | | | | | th)
84
85 # call contour_detect for detect them.
86 self.contour_detect(th)
87
88 # return th copy of the img (with the green rectangle)
89 | | return | | self.copy
90
91
92 | if | | __name__ | | == | | '__main__':
93 # Opening the video file.
94 | | cap | | = | | cv2.VideoCapture("vue_top.mp4")
95 # Creating an object of the class PersonneDetect.
96 | | p | | = | | PersonneDetect()
97
98 | | while | | True:
99 # Reading the next frame from the video file.
100 | | _, | | | img | | = | cap.read()
101 # Resizing the image to a smaller size to make the algorithm faster.
102 # img = cv2.resize(img, (640, 480), interpolation=cv2.INTER_AREA)
103
104 # Calling the function `personne_detect` of the class `PersonneDetect` and
| passing the image `img` as argument.
105 | | img | | = | | p.personne_detect(img)
106
107 # Showing the image in a window named "img".
108 | | cv2.imshow("img", | | | | | | img)
109
110 # Stop the program when the user press the key `q`.
111 | | if | | cv2.waitKey(50) | | | | | == | ord("q"):
112 break
113
114 # Closing the video file and destroying all the windows. 115 cv2.destroyAllWindows()
116 cap.release()
117

1 """ personne_tracking.py | Robin Forestier | 28.03.2022
2
3 [WARN] The camera is placed on top of the door.
4
5 After Personne detection we want to track it.
6 For tracking the displacement of a moving object, I start by calculate his centroid. 7 After I save his last centroid to ave 2 points by moving object.
8 With these points I calculate the euclidean distance to find the nearest.
9 With these 2 points, I know the travel of the personne.
10 """
11
12 # Imports
13 | import | | cv2
14 | import | | numpy | | as | | np
15
16 # It's importing the PersonneDetect class from the personne_detect.py file.
17 | from | | personne_detect | | import | | PersonneDetect
18
19 | class | | PersonneTracking:
20 """Is used for track the trajectory of any people detected by PersonneDetect.""" 21
22 | | def | | __init__(self):
23 """The function initializes the class"""
24 | | self.img | | | | = | | []
25 | | self.prev_img | | | | = | | []
26 | | self.centroide | | | | = | | []
27 | | self.centroide_lp | | | | = | | []
28
29 | | self.inout | | | | = | | []
30
31 | | def | | calc_centroide(self, | | | | | img, | | rects):
32 """Calculate the centroid of the bounding rect
33
34 :param img: The image on which the contour was found
35 :type img: numpy.ndarray
36 :param rects: a list of tuples, where each tuple is (x, y, w, h) 37 :type rects: list
38 """
39
40 | | self.img | | | | = | | img
41 # save the last centroid
42 | | self.centroide_lp | | | | = | | self.centroide
43 | | self.centroide | | | | = | | []
44
45 | | for | | rect | | in | | rects:
46 # It's the coordinates of the point where the line is drawn.
47 | | x | | = | | int(rect[0] | | | | | | + | (rect[2] | | / | 2))
48 | | y | | = | | int(rect[1] | | | | | | + | (rect[3] | | / | 2))
49 self.centroide.append((x,y))
50 # It's drawing a circle on the image.
51 | | cv2.circle(self.img, | | | | | | | | (x, | | | y), | 2, | (0,0, | | 255), | -1)
52
53 # It's calculating the euclidean distance of each centroid and last centroid
| for predict the move of a person.
54 self.centroide_last_pose()
55
56 | | def | | centroide_last_pose(self):
57 """Calculate if the persone is pacing the center line."""
58
59 # to calculate the distance between the points, I start by knowing which
| list is the smallest.
60 | | if | | len(self.centroide) | | | | | | <= | | len(self.centroide_lp):
61 | | pos1 | | = | | np.array(self.centroide)
62 | | pos2 | | = | | np.array(self.centroide_lp)
63 else:
64 | | pos1 | | = | | np.array(self.centroide_lp)
65 | | pos2 | | = | | np.array(self.centroide)
66
67 # pos1 have less points than pos2
68 # It happens when you start to detect or stop detecting someone.
69 | | if | | len(pos1) | | | | | and | len(pos2):
70 # Size off the image

71 | | height | | = | | self.img.shape[0]
72 | | width | | = | | self.img.shape[1]
73
74 # line in the middle of the image.
75 | | cv2.line(self.img, | | | | | | | | (int(width | | | | / | | 2), | | | 0), | | (int(width | | | / | 2), | | height),
| (0,255,255), | | | | | | | | 2, | | cv2.LINE_AA)
76
77 | | for | | i | | in | | range(len(pos1)):
78 # This is the code that is used to find the index of the minimum
| value in the array.
79 | | idx | | = | | np.array([np.linalg.norm(x | | | | | | | | | | + | | y) | | for | | (x, | | y) | | in | pos2 | -
| pos1[i]]).argmin()
80
81 # Draw points and line
82 | | cv2.circle(self.img, | | | | | | | | tuple(pos1[i]), | | | | | | 2, | | | (255, | | | 0, | 0), | | -1)
83 | | cv2.line(self.img, | | | | | | | | tuple(pos1[i]), | | | | | | tuple(pos2[idx]), | | | | | | (255, | | 255, | | 0),
| 5, | | | cv2.LINE_AA)
84
85 # It's checking if the centroid list is smaller than the last
| centroid list.
86 # If it's the case, just invert the two variable.
87 | | if | | len(self.centroide) | | | | | | > | | len(self.centroide_lp):
88 | | i, | | | idx | | = | | idx, | | i
89
90 # It's calculating if the person is moving to the left or to the
| right.
91 | | if | | self.centroide[i][0] | | | | | | | | < | width | | / | | 2 | | < | self.centroide_lp[idx][0]:
92 self.inout.append(1)
93 | | elif | | self.centroide[i][0] | | | | | | | | > | width | | / | | 2 | | > | self.centroide_lp[idx][0]:
94 self.inout.append(0)
95
96
97 @property
98 | | def | | inout(self):
99 """The inout function returns the value of the private variable _inout 100
101 :return: The value of the instance variable _inout
102 :rtype: list
103 """
104 | | return | | self._inout
105
106 @inout.setter
107 | | def | | inout(self, | | | | | value):
108 """Set the value of the private variable _inout 109
110 :param value: The value to be set
111 :type value: list
112 """
113 | | self._inout | | | | = | | value
114
115
116 | if | | __name__ | | == | | '__main__':
117 # It's using the video file to capture the frames.
118 | | cap | | = | | cv2.VideoCapture('vue_top.mp4')
119
120 # It's creating an object of the class PersonneDetect.
121 | | p | | = | | PersonneDetect()
122 # It's creating an instance of the class PersonneTracking.
123 | | pt | | = | | PersonneTracking()
124
125 | | while | | True:
126 # This is a way to reset the video to the first frame if the video is
| finished.
127 | | if | | cap.get(cv2.CAP_PROP_POS_FRAMES) | | | | | | | | == | cap.get(cv2.CAP_PROP_FRAME_COUNT):
128 | | cap.set(cv2.CAP_PROP_POS_FRAMES, | | | | | | | | 0)
129
130 # It's getting the image from the video.
131 | | _, | | | img | | = | | cap.read()
132
133 # It's using the PersonneDetect class to detect people in the image.
134 | | result | | = | | p.personne_detect(img)
135 # It's calculating the centroid of the bounding rect of the detected people.

136 | pt.calc_centroide(result, | | | p.detected)
137
138 # It's showing the image on the screen.
139 | cv2.imshow("result detect", | | | result)
140
141 | prev | = | img
142
143 # It's breaking the loop when the user press the `q` key.
144 | if | cv2.waitKey(70) | | | == | ord('q'):
145 break
146
147 # It's closing the window and release the capture. 148 cv2.destroyAllWindows()
149 cap.release()
150

1 | """entry_detect.py | Robin Forestier | 28.03.2022
2
3 | [WARN] The camera is placed on top of the door.
4
5 | This file is used to detect entry and exit. It uses PersonneDetect & PersonneTracking.
6 | """
7
8 | # Imports
9 | from | | datetime | | import | | datetime
10 | import | | cv2
11 | import | | requests
12
13 | # import personally module
14 | from | | sample.personne_detect | | | | import | | PersonneDetect
15 | from | | sample.personne_tracking | | | | import | | PersonneTracking
16
17
18 | def | | send(info):
19 | | """Send the data to the server
20
21 | :param info: the information to send
22 | :type info: int
23 | """
24
25 | | # It's getting the current time.
26 | | t | | = | | datetime.now()
27 | | current_time | | = | | t.strftime("%H:%M")
28
29 | | # It's opening the file /sys/class/thermal/thermal_zone0/temp and reading the
| temperature.
30 | | try:
31 | | with | | open('/sys/class/thermal/thermal_zone0/temp', | | | | | 'r') | | | as | | ftemp:
32 | | temp | | = | | int(int(ftemp.read()) | | | | | | | | | / | | 1000)
33 | | except | | OSError:
34 | | temp | | = | | 0
35
36 | | # It's creating a string that will be sent to the server.
37 | | data | | = | | "{}{:03d}{}".format(current_time, | | | | | | | temp, | | | info)
38 | | data | | = | | {'data': | | | | '$,RPWCSD,{:03d},{},0*'.format(len(data), | | | | | | | | | data)}
39
40 | | try:
41 | | # It's sending the data to the server.
42 | | # Change the url to your own server.
43 | | r | | = | | requests.post("http://172.16.32.133/camera", | | | | | | | data=data, | | | | | timeout=0.5)
44
45 | | # This is checking if the status code is bigger than 299. If it is, it's
| printing an error message.
46 | | if | | r.status_code | | | | > | | 299:
47 | | print("[Error] Communication error, code : ", | | | | | r.status_code)
48 | | else:
49 | | # It's getting the data from the server.
50 | | data | | = | | r.text
51 | | # if the data is a correct trame ($,...,*)
52 | | if | | data[0] | | | | | == | | "$" | | and | | data[::-1][0] | | | | | == | "*":
53 | | data | | = | | data.split(',')
54
55 | | # Communication OK
56 | | if | | data[1] | | | | | == | | "RPWCOK":
57 | | print("ok")
58 | | # Communication Error
59 | | if | | data[1] | | | | | == | | "RPWCER":
60 | | print("[ERROR] The cam had send a bad trame.")
61
62 | | # It's catching the error if the server is not available.
63 | | except | | requests.exceptions.RequestException | | | | | | as | | e:
64 | | print(e)
65
66
67 | if | | __name__ | | == | | '__main__':
68 | | # It's opening the webcam.
69 | | cap | | = | | cv2.VideoCapture(0)
70

71 | | # It's creating a PersonneDetect object and storing it in the variable `detect`.
72 | | detect | = | | PersonneDetect()
73 | | # It's creating a PersonneTracking object and storing it in the variable
| `tracking`.
74 | | tracking | = | | PersonneTracking()
75
76 | | while | True:
77 | | # It's getting the frame from the webcam.
78 | | ret, | | frame | | = | | cap.read()
79
80 | | # It's resizing the frame to 640x480.
81 | | frame | = | | cv2.resize(frame, | | | | | (640, | 480), | interpolation=cv2.INTER_AREA)
82
83 | | # It's detecting people in the frame.
84 | | frame | = | | detect.personne_detect(frame)
85 | | # It's calculating the centroid of the detected people.
86 | | tracking.calc_centroide(frame, | | | | | | detect.detected)
87
88 | | inouts | = | | tracking.inout
89
90 | | for | inout | | in | | inouts:
91 | | if | inout | | == | | 1:
92 | | print("[INFO] Entrée")
93 | | send(inout)
94 | | else:
95 | | print("[INFO] Sortie")
96 | | send(inout)
97
98 | | tracking.inout.clear()
99
100 | | # It's showing the image in a window.
101 | | cv2.imshow("image", | | | | | | frame)
102
103 | | t | = | | datetime.now()
104 | | print(t.strftime("%H:%M"))
105
106 | | # It's checking if the user press the key "q". If it is, it's breaking the
| loop.
107 | | if | cv2.waitKey(1) | | | | | | == | ord("q"):
108 | | break
109
110 | | # It's closing the webcam and the window.
111 | | cv2.destroyAllWindows()
112 | | cap.release()
113

1 """main.py | Robin Forestier
2
3 Fichier de test pour Opencv
4 """
5
6 # `import cv2` imports the OpenCV library, while `import numpy as np` imports the numpy library.
7 | import | cv2
8 | import | numpy | as | | np
9
10 # Show information about OpenCV
11 print(__doc__)
12 | print("[INFO] Version d'OpenCV : ", | | | cv2.__version__)
13 | print("[INFO] Version de numpy : ", | | | np.__version__)
14 print("\n[INFO] Press any buton to quit.")
15
16 # Reading the image and storing it in the variable `img`.
17 | img | = | cv2.imread("test.png")
18
19 # Displaying the image `img` in a window called `test`.
20 | cv2.imshow("test", | | | | | img)
21
22 # `cv2.waitKey(0)` waits for a key to be pressed. `cv2.destroyAllWindows()` destroys all windows.
23 cv2.waitKey(0)
24 cv2.destroyAllWindows()
25

1 | """test_communication.py | Robin Forestier | 16.02.2022
2
3 | This file is used for communication test with the server flask.
4 | The programme send the current time (13:46), the temperature of the camera (054) for
54°C and a bool value 1 or 0
5 | (1 is for entry).
6 | """
7
8 | # `time` is a module that contains a lot of functions to work with time.
9 | # `datetime` is a module that contains a lot of functions to work with date and time.
10 | import | | time
11 | from | | datetime | | import | | datetime
12
13 | # `requests` is a module that allows to send HTTP requests.
14 | import | | requests
15
16 | while | | True:
17
18 | | # `t` is a variable that contains the current time.
19 | | t | | = | | datetime.now()
20 | | # `strftime` is a function of the `datetime` module. It allows to convert a date
| into a string.
21 | | current_time | | = | | t.strftime("%H:%M")
22
23 | | # Take the temperature of the RPi
24 | | # Error also temp is 0
25 | | try:
26 | | with | | open('/sys/class/thermal/thermal_zone0/temp', | | | | | 'r') | | | as | | ftemp:
27 | | temp | | = | | int(int(ftemp.read()) | | | | | | | | | / | 1000)
28 | | except | | OSError:
29 | | temp | | = | | 0
30
31 | | # Creating a string with the current time and the temperature of the camera.
32 | | data | | = | | "{}{:03d}1".format(current_time, | | | | | | | temp)
33 | | data_length | | = | | len(data)
34 | | data | | = | | {'data': | | | | '$,RPWCSD,{:03d},{},0*'.format(data_length, | | | | | | data)}
35
36 | | print(data)
37
38 | | try:
39 | | # Sending the data to the server (change the ip to your server IP).
40 | | r | | = | | requests.post("http://172.16.32.27/camera", | | | | | | | data=data, | | | | timeout=0.5)
41 | | # Checking if the status code is bigger than 299.
42 | | if | | r.status_code | | | | > | | 299:
43 | | print("[Error] Communication error")
44 | | else:
45 | | # Reading the data send by the server.
46 | | data | | = | | r.text
47 | | # if the data is a correct trame ($,...,*)
48 | | if | | data[0] | | | | | == | | "$" | | and | | data[::-1][0] | | | == | "*":
49 | | data | | = | | data.split(',')
50
51 | | # Communication OK
52 | | if | | data[1] | | | | | == | | "RPWCOK":
53 | | print("ok")
54 | | # Communication Error
55 | | if | | data[1] | | | | | == | | "RPWCER":
56 | | print("[ERROR] The cam had send a bad trame.")
57
58 | | # This is a way to catch all the exceptions that can occur when you try to send
| a request to the server.
59 | | except | | requests.exceptions.RequestException | | | | | | as | | e:
60 | | print(e)
61
62 | | time.sleep(10)
63

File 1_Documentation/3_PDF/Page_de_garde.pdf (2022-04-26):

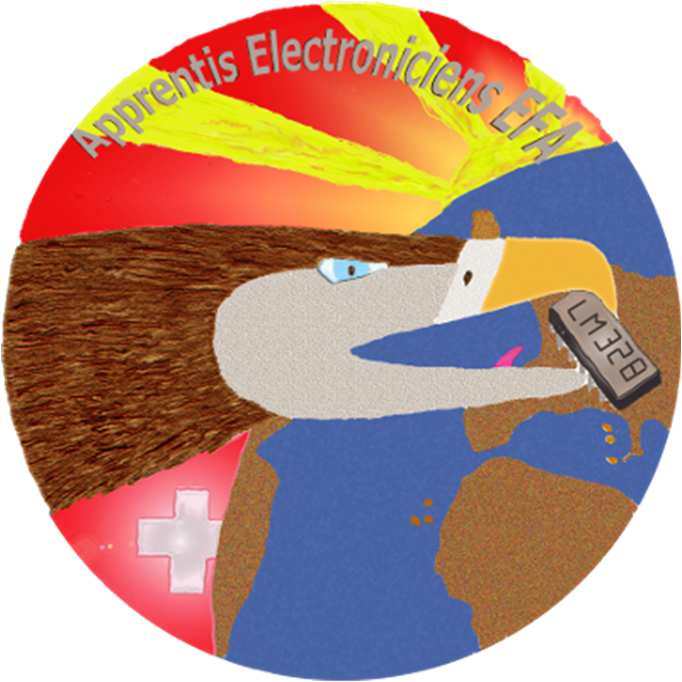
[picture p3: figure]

TPI - Forestier Robin - 2022

Gestion système lumière KNX - EIB

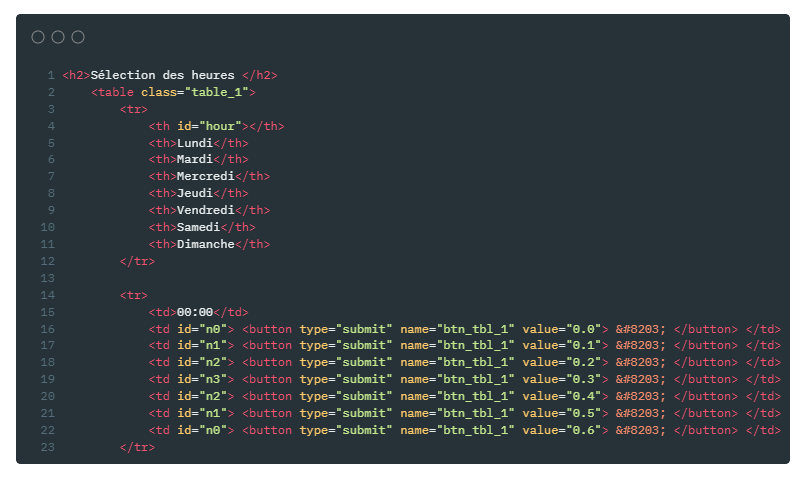
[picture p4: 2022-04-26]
1_Documentation/2_Programmation/table1_render_html.png

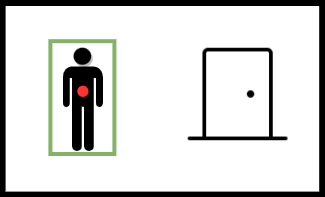
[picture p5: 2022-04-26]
1_Documentation/1_XWiki/exemple_3.PNG

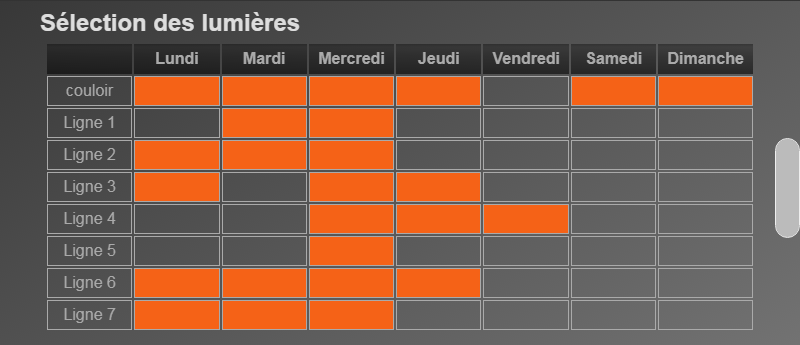
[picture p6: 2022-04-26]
1_Documentation/1_XWiki/table_2.png

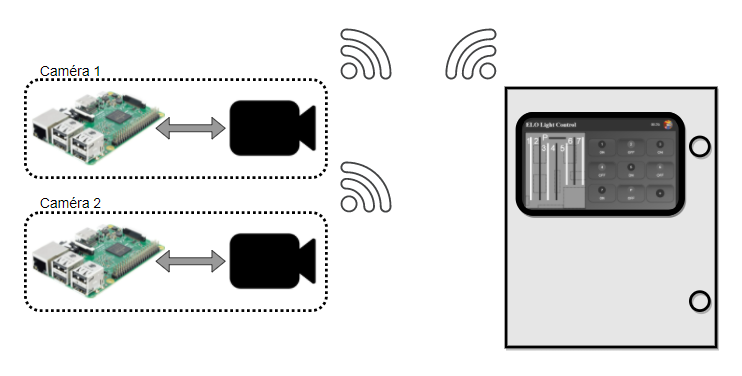
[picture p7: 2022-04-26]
1_Documentation/1_XWiki/shema_global.PNG

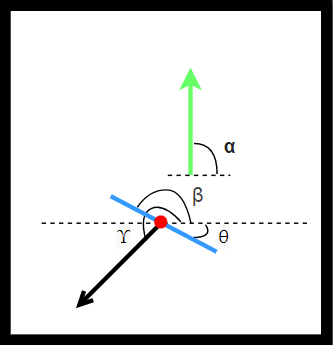
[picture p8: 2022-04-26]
1_Documentation/1_XWiki/exemple_10.PNG

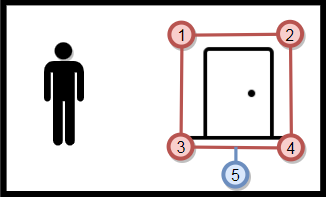
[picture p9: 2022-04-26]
1_Documentation/1_XWiki/exemple_1.PNG

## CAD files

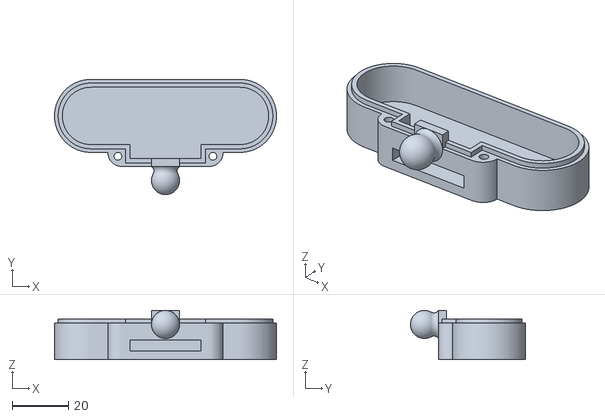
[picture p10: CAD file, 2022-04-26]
4_Fabrication/Version_01/B_Mecanique/2_STL/boitier_cam_v1.stl
79.0 x 41.0 x 17.5

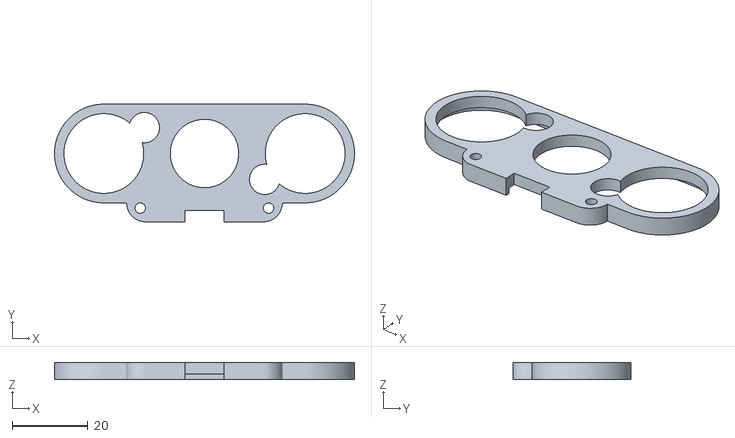
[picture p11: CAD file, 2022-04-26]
4_Fabrication/Version_01/B_Mecanique/2_STL/couvercle_cam_v1.stl
79.0 x 31.0 x 4.50

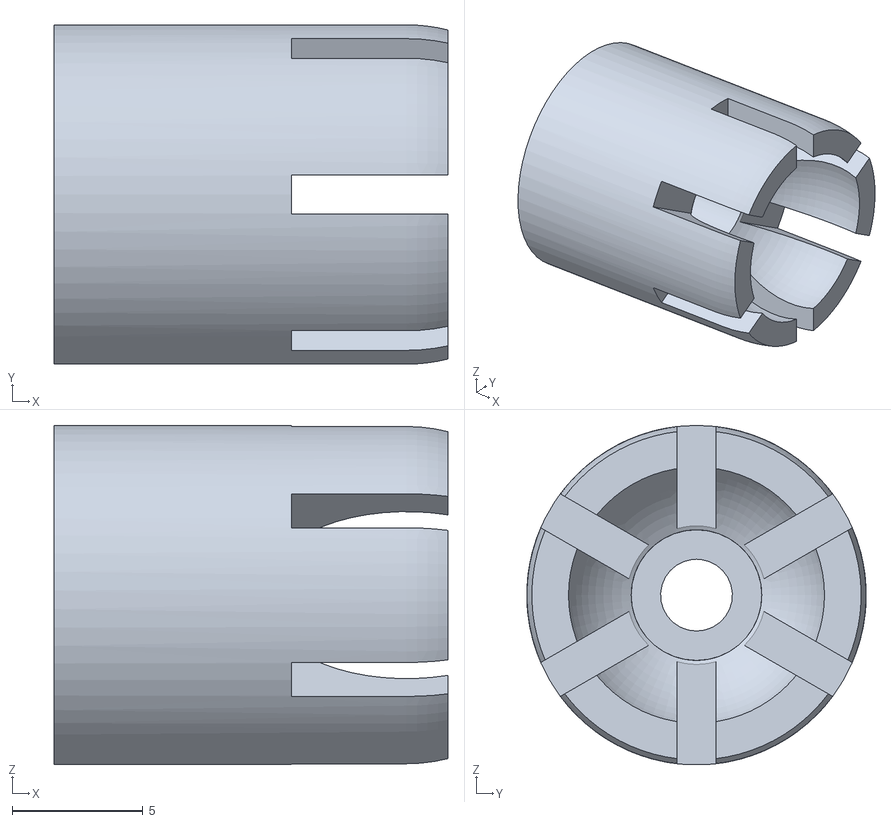
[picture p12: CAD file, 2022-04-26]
4_Fabrication/Version_01/B_Mecanique/2_STL/rotule.stl
15.1 x 13.0 x 13.0

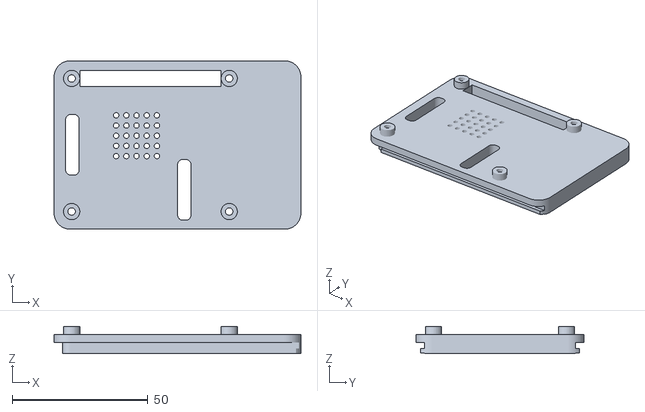
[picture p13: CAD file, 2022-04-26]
4_Fabrication/Version_01/B_Mecanique/2_STL/couvercle_v1.stl
90.9 x 62.0 x 10.0

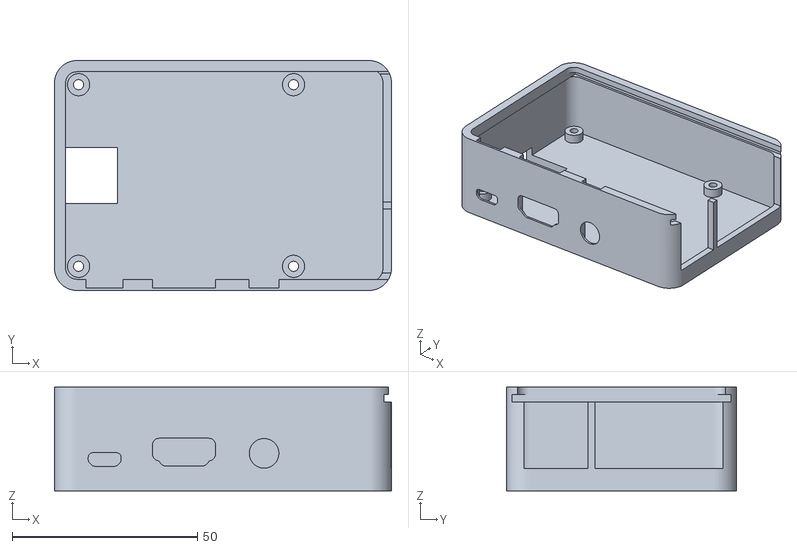
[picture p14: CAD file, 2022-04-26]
4_Fabrication/Version_01/B_Mecanique/2_STL/boitier_v1.stl
90.9 x 62.0 x 28.0

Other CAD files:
4_Fabrication/Version_01/B_Mecanique/1_SolidEdge/fixation_mur.psm

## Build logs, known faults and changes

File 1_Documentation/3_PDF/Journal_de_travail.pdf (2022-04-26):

# Journal de travail

last modified by Forestier Robin
on 2022/04/04 20:53

TPI_Forestier_Gestion_Lumiere_KNX - Journal de travail

# Table of Contents

Page 2 / 7 - last modified by Forestier Robin on 2022/04/04 20:53

Contents
- Semaine 1
- Lundi 7 mars 2022
- Mardi 8 mars 2022
- Mercredi 9 mars 2022
- Semaine 2
- Lundi 14 mars 2022
- Mardi 15 mars 2022
- Mercredi 16 mars 2022
- Semaine 3
- Lundi 21 mars 2022
- Mardi 22 mars 2022
- Mercredi 23 mars 2022
- Semaine 4
- Lundi 28 mars 2022
- Mardi 29 mars 2022
- Mercredi 30 mars 2022
- Semaine 5
- Lundi 4 avril 2022
- Mardi 5 avril 2022

# Semaine 1

## Lundi 7 mars 2022

Matin:
Création du planning (Planning_TPI_FOR_v1) (https://xwiki.serverelo.org:443/xwiki/bin/download/Centre%20de%20Formation%20ELO/Travaux-diplome/TPI_Forestier_Gestion_Lumiere_KNX/Journal%20de%20travail/WebH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) et répartition du temps pour les différentes activités. Planning à jour: Planning_TPI_FOR_v2 (http://172.16.32.230/Forestier/tpi_forestier_gestion_lumiere_knx/1_Documentation/Planning_TPI_FOR_v2.xls)
Création du GitLab avec la structure de fichier de l'atelier. GitLab - TPI_Gestion_Lumiere_KNX (http://172.16.32.230/Forestier/tpi_forestier_gestion_lumiere_knx) Création des deux pages XWiki: Jounal de travail et Documentation (https://xwiki.serverelo.org:443/xwiki/bin/view/Centre%20de%20Formation%20ELO/Travaux-diplome/TPI_Forestier_Gestion_Lumiere_KNX/Documentation/)
Après-midi:
J'ai réalisé toutes les installations nécessaires sur mes 3 Raspberry Pi. (OpenCV / GitLab / ...)
J'ai aussi modifié les paramètres de gunicorn et de nginx sur le Raspberry Pi serveur pour que les liens vers le nouveau dossier de travail soit correct.
Gunicorn : /etc/systemd/system/lightcontrol.service
NginX : /etc/nginx/sites-available/lightcontrol
J'ai aussi commencé la programmation, en réalisant la sélection des portes. Le programme est normalement fonctionnel mais pas complètement commenté.

## Mardi 8 mars 2022

Matin:
J'ai commencé par commenter complètement le fichier Select_door.py.
J'ai réalisé un script pour la détection des portes grâce au "matching template". Ce code pourra être utile si la caméra bouge de sa position initiale.
J'ai ensuite commencé la détection des personnes. Pour détecter les personnes, je réalise une soustraction d'images avec l'algorithme (createBackgroundSubtractorKNN). Mes résultats actuels sont fiables et utilisables mais peuvent être améliorés.
Après-midi:
Création d'un code plus structuré et documenté (personne_detect.py) et création de la class PersonneDetect. J'ai aussi pu réaliser des tests pour le calcul de l'angle de déplacement permettant de savoir la trajectoire de la personne en mouvement.

Page 3 / 7 - last modified by Forestier Robin on 2022/04/04 20:53

## Mercredi 9 mars 2022

Matin:
Avec les tests d'hier après-midi, j'ai pu créer le code personne_tracking.py et la class PersonneTracking. Je peux dès à présent calculer l'angle de déplacement d'un objet en mouvement ou d'une personne.
Le tracking n'est pas efficace à 100% mais suffit pour ce projet.
Après-midi:
J'ai connecté les Raspberry Pi sur les serveurs NTP Suisse (ch.pool.ntp.org).
J'ai réalisé quelques améliorations sur le tracking des personnes.
J'ai pu remarquer plusieurs problématiques. Premièrement, si deux personnes se trouvent proches, le système ne les différenciera pas. Deuxièmement, je dois encore réaliser un tri des résultats car on trouve des faux positifs dans la détection.
J'ai aussi décelé plusieurs améliorations possibles au système, comme un positionnement des caméras au-dessus des portes regardant directement le sol. Cela simplifierait la détection et permettrait un comptage précis des personnes.
Après discussion avec Monsieur Dupertuis, je vais terminer proprement la détection des personnes et
commencer l'interface graphique. Je vais aussi simplifier un peu la détection et s'il me reste du temps à la fin de mon TPI, je reviendrai dessus.

# Semaine 2

## Lundi 14 mars 2022

Matin:
J'ai optimisé le code entry_detect.py en réalisant un tri des informations dans la class info.
Pour valider la sortie ou l'entrée d'une personne, il faut au minimum trois fois des informations de détection identiques. Cela vient simplement diminuer le nombre d'erreurs et augmente le pourcentage de détections correctes.
Après-midi:
J'ai terminé l'optimisation du code entry_detect.py. Il est maintenant fonctionel.
Il me faudra encore tester les caméras avec la vision nocturne.
J'ai discuté avec Monsieur Dupertuis pour clarifier deux points de mon cahier des charges:
1. Sur le tableau, les cases bleues représentent une extinction automatique (sans prendre en compte les caméras).
2. L'accès aux settings depuis l'écran tactile doit se faire avec un mot de passe. Mais ce mot de passe doit pouvoir être rentré sans clavier externe.
Pour ce deuxième point, il faudra que l'utilisateur puisse taper le mot de passe sur un clavier visible sur l'écran.

## Mardi 15 mars 2022

Matin:
Pour répondre à la problématique du mot de passe pour l'écran tactile, j'ai créé la page login 2.
Cette page est uniquement accessible si on se connecte depuis le serveur. Cette page affiche un clavier avec les chiffres de 0 à 9 avec un bouton "effacer" et un bouton "submit".
Création de la page HTML settings est gestion des autorisations pour l'utilisateur "local" (écran tactile). Après-midi:
Amélioration de la page settings et ajout des différentes sections.
- Tableau 1.

Page 4 / 7 - last modified by Forestier Robin on 2022/04/04 20:53

- Tableau 2.
- Ajout des heures.
- Mode manuel.
- Heures manuelles.
- Caméras.
- Modification des mots de passe.

## Mercredi 16 mars 2022

Matin:
Implémentation de l'heure et de la date manuelle. Pour cela je viens récupérer uniquement le jour de la semaine et la différence de temps entre l'heure réelle et l'heure entrée par l'utilisateur. Quand le système récupère l'heure pour l'afficher il reçoit l'heure plus la différence.
J'ai aussi réalisé la réinitialisation du système à minuit.
Après-midi:
Sous la section caméras dans la page settings, les champs Online et Offline se mettent à jour automatiquement. Pour le savoir, je réalise un "ping" sur l'adresse IP de chacune des caméras. Cette action est réalisée dans la fonction run_job.
J'ai aussi commencé la communication entre les caméras et le serveur WEB. La communication se fait grâce à une request http envoyée sur une page non accessible par les utilisateurs. Pour reconnaître une caméra, je viens vérifier son adresse MAC (après discussion avec Monsieur Dupertuis) et non son adresse IP.

# Semaine 3

## Lundi 21 mars 2022

Matin:
J'ai commencé l'implémentation de la lecture des tables horaires. J'ai pu ajouter l'extinction automatique et l'allumage automatique des lumières suite à une requête des caméras.
Mais un problème de Wi-Fi est arrivé et a stoppé mon avance. Je vais donc réaliser de la documentation jusqu'au retour du Wi-Fi.
Après-midi:
Après rétablissement de la connexion Wi-Fi, j'ai pu reprendre et j'ai enfin passé le serveur sur le Raspberry Pi. Je me suis heurté à un problème. Le système n'arrivait pas à exécuter les commandes Ping et Arp.

## Mardi 22 mars 2022

Matin:
Après plus amples vérifications j'ai découvert que le problème venait de la configuration de mon serveur Gunicorn.
Après cette modification le programme était de nouveau fonctionnel.
J'ai enfin pu tester l'entièreté de mon projet.
J'ai remarqué quelques petits bugs qui ont été corrigés.
1. La sauvegarde des portes ne se faisait pas dans le bon dossier.
2. L'affichage online/offline des caméras ne fonctionnait pas.
Après quelques tests, j'ai remarqué que mon projet fonctionnait selon mon cahier des charges, mais la détection n'est pas à la hauteur pour les deux portes les plus éloignées des caméras.
Je vais d'abord essayer de trouver une autre place pour cette caméra.

Page 5 / 7 - last modified by Forestier Robin on 2022/04/04 20:53

J'ai marqué plus haut qu'un comptage était possible avec les caméras positionnées directement au-dessus des portes, je discuterai de cela avec Monsieur Dupertuis demain pour proposer cette amélioration au vu de mon avance sur le planning.
Après-midi:
Après discussion avec Monsieur Dupertuis, il m'a conseillé de solidifier mon projet et assurer qu'il répond au cahier des charges avant de me lancer dans l'amélioration.
Mise à jour de l'entièreté des commentaires dans mes différents codes.

## Mercredi 23 mars 2022

Matin:
Explication détaillée du fonctionnement du système dans ma documentation.
Après-midi:
Explication de la programmation du système et du calcul des angles dans ma documentation.

# Semaine 4

## Lundi 28 mars 2022

Matin:
J'ai commencé la réalisation de l'amélioration.
Pour cela, j'ai filmé plusieurs personnes entrer et sortir avec la caméra placée au-dessus de la porte.
J'ai pu réutiliser mes codes: personne_detect, personne_tracking et entry_detect. Mais j'ai supprimé tous les calculs d'angles et je les ai simplifiés.
La détection marche très bien, il faudra encore la tester en condition réelle mais les résultats sont pour le moment excellents.
Après discussion avec Monsieur Dupertuis, je vais tester cette nouvelle méthode de détection sur deux des trois portes, car pour la porte rouge, il faudra réaliser des travaux pour la fixation de la caméra, cela sera réalisé après le TPI si la détection est fonctionnelle.
Après-midi:
J'ai fixé les deux caméras sur du bois pour leur ajouter du poids et j'ai ensuite réalisé 2 rallonges pour les raccorder.
Après plusieurs tests concluants, j'ai ajouté un comptage des personnes.
Pour réaliser un test plus réel de mon système, je vais le laisser fonctionner et regarder demain matin si les personnes ont été comptées.

## Mardi 29 mars 2022

Matin:
Le test que j'ai voulu réaliser n'a pas fonctionné car le programme de la caméra a "freeze" au milieu de la nuit.
Je pense que le problème vient de la température du Raspberry. Après redémarrage le comptage a bien fonctionné. Après-midi:
J'ai réalisé le branchement de la deuxième caméra à travers le faux plafond.
J'ai pu tester le système avec les deux caméras en fonction.
J'ai aussi ajouté la vérification du comptage avant extinction automatique.

## Mercredi 30 mars 2022

Matin:

Page 6 / 7 - last modified by Forestier Robin on 2022/04/04 20:53

J'ai de nouveau laissé les caméras activées toutes la nuit, le même phénomène s'est produit. Après un certain temps les caméras "freez".
J'ai donc essayé plusieurs modifications pour trouver d'où vient le problème.
Premièrement, j'ai affiché la température en temps réel. Au moment du "freez" la température était encore de 80°C et n'avait pas varié depuis longtemps. J'ai ensuite essayé de lancer mon programme en "nohup", en arrièrre-plan. Sans changement.
Après-midi:
J'ai poursuivi les tests en vérifiant l'utilisation de la mémoire et du CPU.
J'ai aussi lancé le programme en mode debug.
Le programme semble toujours se stopper à la demande de l'image à la caméra. Je vais ventiler mon Raspberry Pi et la caméra pour faire descendre la température.

# Semaine 5

## Lundi 4 avril 2022

Matin:
Après tous les tests de la semaine dernière, je pense que la température de la caméra devient après une longue période de temps, trop élevée. Ce qui stoppe celle-ci.
Pour le tester, je vais utiliser un Fluke et un thermocouple pour mesurer sa température.
Avec une température ambiante à 24°C, ma caméra monte en moins d'une heure à 65°C et les LED infrarouge à 70°C. Je vais donc ajouter des dissipateurs thermiques et refaire ces mesures.
Après-midi:
Avec les dissipateurs thermiques, la température n'augmente pas au-dessus de 55°C environ.
J'ai créé les deux images de mes Raspberry Pi.
Liens:
OMVSERVER\formation\TPI\TPI_Forestier_Gestion_Lumiere_KNX, RPi_server.img et RPi_camera.img.

## Mardi 5 avril 2022

Matin:
Finalisation de la documentation.
Après-midi:
Impression des documents et des codes. Rendu du projet, fin du TPI.

Page 7 / 7 - last modified by Forestier Robin on 2022/04/04 20:53

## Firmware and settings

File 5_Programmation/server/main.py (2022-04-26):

"""main.py | Robin Forestier | 2021 / 2022

Goal : Create a user interface to control the light of the ELO's workshop.

Explanation :   I use Flask for create a Web server.
                A shield is plug on the Raspberry Pi (server) with opto-isolator to ABB module with the GPIO.

TPI : For my IPT, I have to create a settings page controlling the time range where the cameras have the right
      to request a modification of the lights.
      I have to create a manual mode, to modify the date and time. I also need to see the status of the cameras and be
      able to change the passwords.

Raspberry Pi pinout usage :
    +---------------------------------+
    | Raspberry Pi 3B+                |  +------------------------+
    |                            +--+ |  | Shield Octo            |
    |                            |  | |  |                        |
    |          GPIO 2  |         |  | |  | X1 / DRV3 |            |
    |          GPIO 3  |         |  | |  | X1 / DRV4 |            |
    |          GPIO 4  |         |  | |  | X2 / DRV1 |            |
    |                  |         |  | |  |           |            |
    |          GPIO 10 |         |  | |  | X3 / DRV3 |            |
    |          GPIO 9  |         |  | |  | X3 / DRV2 |            |
    |          GPIO 11 | GPIO 8  |  | |  | X3 / DRV4 | X3 / DRV1  |
    |                  | GPIO 7  |  | |  |           | X2 / DRV4  |
    |          GPIO 0  | GPIO 1  |  | |  | X1 / DRV1 | X1 / DRV2  |
    |          GPIO 5  |         |  | |  | X2 / DRV2 |            |
    |          GPIO 6  |         |  | |  | X2 / DRV3 |            |
    |                            |  | |  +------------------------+
    |                            |  | |
    |                            +--+ |
    |                                 |
    |                     +-------+   |
    |  +----+   +----+    |       |   |
    |  |    |   |    |    |       |   |
    |  |    |   |    |    |       |   |
    +--+----+---+----+----+-------+---+

GitLab : http://172.16.32.230/Forestier/controle-des-lumieres-knx
         http://172.16.32.230/Forestier/tpi_forestier_gestion_lumiere_knx
XWiki :
    https://xwiki.serverelo.org/xwiki/bin/view/Centre%20de%20Formation%20ELO/Projets/Controle%20des%20lumières%20KNX/
    https://xwiki.serverelo.org/xwiki/bin/view/Centre%20de%20Formation%20ELO/Travaux-diplome/
    TPI_Forestier_Gestion_Lumiere_KNX/Documentation/
"""

# Importing the necessary modules to run the code.
import logging
import os
import pickle
import subprocess
import threading
import time
from datetime import datetime, timedelta
import numpy as np

# Import flask
from flask import Flask, render_template, request, session, url_for, redirect, flash, abort
from flask_session import Session
from flask_sqlalchemy import SQLAlchemy
from werkzeug.exceptions import HTTPException

# Creating a class called Table.
from table.table import Table
# Creating a class called Table2 that inherits from Table.
from table.table import Table2

# The above code is importing the RPi.GPIO module and setting it to use the BCM pin numbering scheme.
try:
    import RPi.GPIO as GPIO

    GPIO.setmode(GPIO.BCM)
    GPIO.setwarnings(False)

    # GPIO 0 to 11 in output mode at 0
    for i in range(12):
        GPIO.setup(i, GPIO.OUT, initial=GPIO.LOW)

    # it's a raspberry pi !
    rpi = True
except ImportError:
    # it's not a raspberry pi !
    rpi = False

# The above code is creating a log file called log.log and setting the format of the log file to the time, the level of
# the log message and the message itself.
logging.basicConfig(filename="log.log", format='%(asctime)s - %(levelname)s - %(message)s', level=logging.INFO)

# This is creating a new Flask object.
app = Flask(__name__)

# This is the configuration for the application.
app.config.update(
    SECRET_KEY='somesecretkeythatonlyishouldknow',
    SQLALCHEMY_DATABASE_URI="sqlite:///db.sqlite3",
    SQLALCHEMY_TRACK_MODIFICATIONS=False,
    SESSION_TYPE='sqlalchemy',
    SESSION_COOKIE_NAME='MyBeautifulCookies',
    SESSION_COOKIE_SAMESITE='Strict',
)

# This is creating a database object that will be used to access the database.
db = SQLAlchemy(app)
# This is telling Flask to use SQLAlchemy as the database.
app.config['SESSION_SQLALCHEMY'] = db
# This is creating a session object that will be used to store and retrieve session data from the user's browser.
sess = Session(app)
db.create_all()

# Ip of the server (for the local user) use to skip authentication.
# Checking if the IP address of the machine that is running the script is in the list of IP addresses that are
# automatically login.
authorize_ip = ["localhost", "127.0.0.1", "172.16.32.133"]

# Value of the buttons and the colors for the map light, each element is a string "off".
buttonSts_p1 = ["off"] * 8
buttonSts_p2 = ["off"] * 8
color = ["#333333"] * 8
# possible warning (like temp alert).
warning = ""


class User:
    """User : create different user for the login"""

    def __init__(self, id, username, password):
        """
        The __init__ function is a constructor method that is called when an object is created

        :param id: The id of the user
        :type id: int
        :param username: The username of the user
        :type username: str
        :param password: The password of the user
        :type password: str
        """

        self.id = id
        self.username = username
        self.password = password


# For the page: login 2
mot_de_pass = []

mode_manuel = 0
"""mode_manuel (int) is set if a user activate it on the settings page. (0 -> disable, 1 -> enable)"""

mode_heure_manuel = [0, 0, 0]
"""mode_heure_manuel (list) is use to store:
1. (boolean) set if mode heure manuel activated.
2. (int) current day. 0 to 6 -> 0 is monday.
3. () delta time.
"""

cam_connect = [[False, "", "b8:27:eb:26:5a:95", 0], [False, "", "b8:27:eb:ce:4f:78", 0]]
"""cam_connect (list) of the authorized camera.
To check the authorisation, I used the mac adresse.
1. (str) True if connected.
2. (str) Ip adresse.
3. (str) Mac adresse.
"""

# This is a timedelta object. It is a duration expressing the difference between two dates.
TURNOFFTIME = timedelta(minutes=1)
"""TURNOFFTIME (timedelta) is the time duration before the light turn off."""

cam_send_turn_off = []

number_of_people = 0
"""number_of_people (int) is the number of people in the room."""

# Try to open password.pickle. this file contains the 3 passwords.
try:
    # This code is opening a pickle file and reading it.
    with open('password.pickle', 'rb') as f:
        # This code is loading the pickle file.
        password = pickle.load(f)
except OSError:
    # This code is creating a pickle file that contains a list of passwords.
    with open('password.pickle', 'wb') as f:
        password = ["elo", "admin", "1234"]
        pickle.dump(password, f, pickle.HIGHEST_PROTOCOL)

users = []
"""
user (list) is a list of User objects.
    elo - basic user / can only modifie light
    admin - all access (settings access)
    local - only used for the raspberry why the touchscreen (server) / can access to settings with login page 2 
            / don't have to login to control the light.
"""
# Create the users.
users.append(User(id=1, username='elo', password=password[0]))
users.append(User(id=2, username='admin', password=password[1]))
users.append(User(id=3, username='local', password=password[2]))


def gpio_modif():
    """gpio_modif : modif all gpio"""
    if rpi:
        for i in range(8):
            if buttonSts_p1[i] == "off":
                # OFF
                GPIO.output(i, 0)
            else:
                # ON
                GPIO.output(i, 1)
                # time.sleep(1)     #security time for fuses
    else:
        pass


def get_time():
    """Get the current time and day

    :return: A tuple containing the current time and the current day of the week.
    :rtype: tuple
    """

    # The above code is creating a global variable called mode_heure_manuel.
    global mode_heure_manuel

    # This code is checking if the first element of the list mode_heure_manuel is equal to 1.
    # If the first element is 1 the mode hour manuel is set.
    # The current hour become current hour + delta time.
    if mode_heure_manuel[0] == 1:
        t = datetime.now() + mode_heure_manuel[2]
        current_time = t.strftime("%H:%M")
        current_day = mode_heure_manuel[1]
    else:
        # Creating a time object.
        t = time.localtime()
        # The above code is creating a string of the current time in hours and minutes (10:10).
        current_time = time.strftime("%H:%M", t)
        # This code is checking the current day of the week and then using that to determine
        # which day of the week it is (0 is monday, 6 is sunday).
        current_day = datetime.today().weekday()

    return current_time, current_day


def myping(host):
    """myping : check if a host is up

    :param host: The host to check.
    :type host: str
    :return: True if the host is up, False if not.
    :rtype: bool
    """

    # Checking if the host is empty. If it is empty, it will return False.
    if host == "":
        return False

    if rpi:
        # This code is using the subprocess module to run the ping command on a host.
        response = str(subprocess.check_output(["ping", "-c", "1", host]))
    else:
        # This code is using the os.popen() function to ping the host.
        response = os.popen("ping -n 1 " + host).read()

    # The above code is checking to see if the ping was successful.
    if "0 received" in response:
        return False
    else:
        return True


def getmacadd(host):
    """getmacadd : get the mac adresse of a host

    :param host: The host to check.
    :type host: str
    :return: The mac adresse of the host.
    :rtype: str
    """

    # This code is using the ping function to ping the host.
    rep = myping(host)
    if rep:
        # The above code is using the subprocess module to run the arp command on the host machine. The arp command is
        # used to display the ARP (Address Resolution Protocol) table. The arp table contains the hardware (MAC) address
        # for each IP address on the local area network.
        answer = str(subprocess.check_output(["arp", "-a", host]))

        if "aucune" in answer:
            return False
        else:
            # Splitting the answer into a list of words.
            answer = answer.split(" ")
            # Return only the MAC address
            return answer[3]
    else:
        return False


@app.errorhandler(HTTPException)
def handle_exception(e):
    """handle_exception : handle http error

    :param e: The http error.
    :type e: HTTPException
    :return: The HTML error page.
    :rtype: render_template
    """

    e = str(e)  # 404 not ...  :  The request URL ...
    code = e.split(":")  # 404 Not Found

    # This is a function that takes in an error code and returns the error page for that error.
    return render_template('404.html', error=code[1], title=code[0]), code[0][0:3]


@app.route("/login", methods=['POST', 'GET'])
@app.route("/", methods=['POST', 'GET'])
def login():
    """login : login page
    Receive from POST : username / password
    We first check if username existe and after password.
    If it's a bad username or pass we flash the error.

    :return: The login page.
    :rtype: render_template
    """

    # Creating a variable called current_time that is equal to the current time.
    current_time, _ = get_time()
    # This code is getting the user's IP address and returning it.
    ip = request.environ.get('HTTP_X_REAL_IP', request.remote_addr)

    # check for authorized ip
    for i in authorize_ip:
        if ip == i:
            logging.info("create local user" + str(ip))
            session['user_id'] = 3
            return redirect(url_for('page1'))

    # This code is checking to see if the user is logged in.
    # If they are, then they will be directed to the page 1.
    if session.get("user_id") is not None:
        return redirect(url_for('page1'))

    # This code is checking to see if the request method is a POST. If it is, it will run the code below.
    if request.method == 'POST':
        # This code is removing the user_id from the session.
        session.pop('user_id', None)

        username = request.form['username']
        password = request.form['password']

        try:
            # This code is using a list comprehension to search for a user with a given username.
            user = [x for x in users if x.username == username][0]
            # The above code is checking if the user exists and if the password is correct.
            if user and user.password == password:
                # Login accepted
                session['user_id'] = user.id
                logging.info("New login username : " + username + " ip : " + str(ip))
                return redirect(url_for('page1'))
            elif user.password != password:
                # bad password, logging it and flash the error
                logging.warning("bad password : " + username + " ip : " + str(ip))
                flash("Bad password")

            return redirect(url_for('login'))

        except IndexError:
            # bad username, logging it and flash the error
            logging.warning("bad username : " + username + " ip : " + str(ip))
            flash("Bad username")
            return redirect(url_for('login'))

    return render_template("login.html", time=current_time, warning=warning)


@app.route("/login2", methods=['POST', 'GET'])
def login2():
    """The login2 function is the second page of the login page.
    It is only for the touch screen. It is called when the user want to go in the settings page.
    It checks if the user has entered the correct password. If the user has entered the correct
    password, the user is redirected to the settings page.

    :return: The login2.html template is being returned.
    :rtype: render_template
    """

    # Creating a function that will return the current time.
    current_time, _ = get_time()
    # This code is getting the user's IP address and returning it.
    ip = request.environ.get('HTTP_X_REAL_IP', request.remote_addr)

    # The above code is checking if the IP address of the user is in the list of authorized IP addresses.
    if ip not in authorize_ip:
        return redirect(url_for('login'))

    global mot_de_pass

    # This code is checking to see if the request method is a POST. If it is, it will run the code below.
    if request.method == 'POST':
        button_click = request.form.get('btn')

        # Checking if the button click is a number between 0 and 9.
        if button_click in ["0", "1", "2", "3", "4", "5", "6", "7", "8", "9"]:
            # The above code is adding in the list all the buttons that are clicked.
            mot_de_pass.append(button_click)

        # Checking if the button click is 10 (Effacer)
        if button_click == "10":
            # Clear the list
            mot_de_pass = []

        # Checking if the button click is 11 (Submit)
        if button_click == "11":
            # The code above is taking the list of characters and joining them together to form a string.
            mot_de_pass = "".join(mot_de_pass)
            # This code is using a list comprehension to find the user named "local" and then returning that user.
            user = [x for x in users if x.username == "local"][0]
            # The above code is checking if the password entered by the user is the same as the password stored in the
            # database.
            if mot_de_pass == user.password:
                mot_de_pass = []
                return redirect(url_for('settings', authorized=1))

            mot_de_pass = []

    return render_template('login2.html', mdp=mot_de_pass, time=current_time, warning=warning)


@app.route("/page1", methods=['POST', 'GET'])
def page1():
    """This function is used to display the page 1
    It is the first page of the application.

    :return: The html page is being returned.
    :rtype: render_template
    """

    # Creating a function that will return the current time.
    current_time, _ = get_time()

    # This code is checking to see if the user is logged in. If they are not logged in, then they are redirected to the
    # login page.
    if session.get("user_id") is None:
        return redirect(url_for('login'))

    # This code is checking if all the elements in the list are equal to "on".
    if all(elem == "on" for elem in buttonSts_p1):
        # Button "all on" in page 2 is turn to "on"
        buttonSts_p2[0] = "on"
    else:
        buttonSts_p2[0] = "off"

    # This code is checking to see if the request method is a POST. If it is, it will run the code below.
    if request.method == 'POST':
        # Checking if the button has been pressed.
        if request.form['button_p1'] == '1':
            if buttonSts_p1[0] == "on":
                buttonSts_p1[0] = "off"
                color[0] = "#333333"
            else:
                buttonSts_p1[0] = "on"
                color[0] = "#FFFFFF"
        elif request.form['button_p1'] == '2':
            if buttonSts_p1[1] == "on":
                buttonSts_p1[1] = "off"
                color[1] = "#333333"
            else:
                buttonSts_p1[1] = "on"
                color[1] = "#FFFFFF"
        elif request.form['button_p1'] == '3':
            if buttonSts_p1[2] == "on":
                buttonSts_p1[2] = "off"
                color[2] = "#333333"
            else:
                buttonSts_p1[2] = "on"
                color[2] = "#FFFFFF"
        elif request.form['button_p1'] == '4':
            if buttonSts_p1[3] == "on":
                buttonSts_p1[3] = "off"
                color[3] = "#333333"
            else:
                buttonSts_p1[3] = "on"
                color[3] = "#FFFFFF"
        elif request.form['button_p1'] == '5':
            if buttonSts_p1[4] == "on":
                buttonSts_p1[4] = "off"
                color[4] = "#333333"
            else:
                buttonSts_p1[4] = "on"
                color[4] = "#FFFFFF"
        elif request.form['button_p1'] == '6':
            if buttonSts_p1[5] == "on":
                buttonSts_p1[5] = "off"
                color[5] = "#333333"
            else:
                buttonSts_p1[5] = "on"
                color[5] = "#FFFFFF"
        elif request.form['button_p1'] == '7':
            if buttonSts_p1[6] == "on":
                buttonSts_p1[6] = "off"
                color[6] = "#333333"
            else:
                buttonSts_p1[6] = "on"
                color[6] = "#FFFFFF"
        elif request.form['button_p1'] == '8':
            if buttonSts_p1[7] == "on":
                buttonSts_p1[7] = "off"
                color[7] = "#333333"
            else:
                buttonSts_p1[7] = "on"
                color[7] = "#FFFFFF"
        elif request.form['button_p1'] == 'page_2':
            return redirect(url_for('page2'))
        else:
            pass

        gpio_modif()

    return render_template('page1.html', button=buttonSts_p1, color=color, time=current_time, warning=warning)


@app.route("/page2", methods=['POST', 'GET'])
def page2():
    """This function is used to display the page 2
    It is the second page of the application.

    :return: The page is being rendered.
    :rtype: render_template
    """

    # Creating a variable called current_time that is equal to the current time.
    current_time, _ = get_time()

    # This code is checking to see if the user is logged in. If they are not logged in, then they are redirected to the
    # login page.
    if session.get("user_id") is None:
        return redirect(url_for('login'))

    # This code is checking to see if the request method is a POST. If it is, it will run the code below.
    if request.method == 'POST':
        # All on
        if request.form['button_p1'] == '1':
            buttonSts_p2[0] = "on"
            for i in range(8):
                buttonSts_p1[i] = "on"
                color[i] = "#FFFFFF"
        # All off
        elif request.form['button_p1'] == '2':
            buttonSts_p2[1] = "off"
            for i in range(8):
                buttonSts_p1[i] = "off"
                buttonSts_p2[i] = "off"
                color[i] = "#333333"
        # 1 / 2
        elif request.form['button_p1'] == '3':
            buttonSts_p2[0] = "off"
            buttonSts_p2[1] = "off"

            for i in range(0, 8, 2):
                color[i] = "#FFFFFF"
                color[i + 1] = "#333333"

                buttonSts_p1[i] = "on"
                buttonSts_p1[i + 1] = "off"
        # Left
        elif request.form['button_p1'] == '4':
            buttonSts_p2[0] = "off"
            buttonSts_p2[1] = "off"

            for i in range(0, 8):
                if i < 3:
                    color[i] = "#FFFFFF"
                    buttonSts_p1[i] = "on"
                else:
                    color[i] = "#333333"
                    buttonSts_p1[i] = "off"
        # Right
        elif request.form['button_p1'] == '5':
            buttonSts_p2[0] = "off"
            buttonSts_p2[1] = "off"

            for i in range(0, 8):
                if i > 3 and i != 7:
                    color[i] = "#FFFFFF"
                    buttonSts_p1[i] = "on"
                else:
                    color[i] = "#333333"
                    buttonSts_p1[i] = "off"

        elif request.form['button_p1'] == 'page_1':
            return redirect(url_for('page1'))
        else:
            pass

        gpio_modif()

    return render_template('page2.html', button=buttonSts_p2, color=color, time=current_time, warning=warning)
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
